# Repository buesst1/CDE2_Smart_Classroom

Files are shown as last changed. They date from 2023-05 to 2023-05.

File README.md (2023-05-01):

<!-- Improved compatibility of back to top link: See: github-link -->

<!-- logo einfügen mit Ordner namens "images" -->
<br />
<div align="center">
  <a href="https://github.com/buesst1/CDE2_Smart_Classroom">
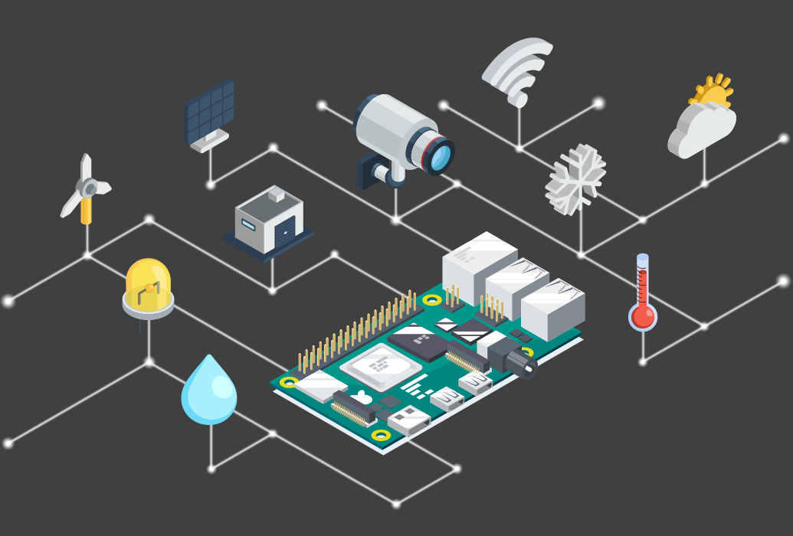
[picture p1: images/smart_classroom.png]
    
  </a>

  <h2 align="center">Smart Classroom</h3>

  <p align="center">
    In diesem Repository wird die Smart Classroom Challange des Studienganges BSc Datascience der Fachhochschule Nordwestschweiz berarbeitet.
    <br />
    Ziel dieser Challenge ist es mithilfe von IoT- Sensoren die optimalen Lüftungsparameter für ein Schulzimmer zu definieren.
    <br />
    Sie finden die Firmware, den Aufbau der Mikrokontroller, die 3D-Druckdateien der Gehäuse sowie die gesamte Datenanalyse.
  </p>
</div>

<!-- TABLE OF CONTENTS -->
  <summary><h2>Inhaltsverzeichnis<h3 /></summary>
  <ol>
    <li><a href="#projektbeschrieb">Projektbeschrieb</a></li>
    <li><a href="#Repository-Aufbau">Repository-Aufbau</a></li>
    <li><a href="#Datenablauf">Datenablauf</a></li>
    <li><a href="#Firmware">Firmware</a></li>
    <li><a href="#Hardware">Hardware</a></li>
    <li><a href="#kontakt">Kontakt</a></li>
  </ol>

<!-- PROJEKTBESCHRIEB -->
### Projektbeschrieb
Mittels verschiedenen Mikrokontroller und Sensoren wird eine automatisierte Datenübertragung auf eine Relationale Datenbank gewährleistet.
<br />
Die Daten wurden im Schulzimmer einer Primarklasse erhoben und anschliessend in diversen Jupyter Notebooks analysiert.
<br />
Um die Mikrokontroller zu schützen wurden Gehäuse konstruiert und anschliessend mit einem SLS 3D-Drucker produziert.
<br />

<p align="right">(<a href="#readme-top">back to top</a>)</p>

<!-- Repository-Aufbau -->
### Repository-Aufbau

:file_folder: Abgabe komplett -> Alle benötigten Dateien und Skripte in einem Ordner zusammengefasst <br />
:file_folder: Box -> Enthält die STL-Dateien für den 3D-Druck der Gehäuse <br />
:file_folder: Hardware -> Die wichtigsten Informationen und Beschriebe der Hardware <br />

<p align="right">(<a href="#readme-top">back to top</a>)</p>

<!-- Datenablauf -->
### Datenablauf

Die Sensordaten wurden insgesamt von drei Mikrokontroller aufgenommen und mittels BLE an einen Raspberrypi zero gesendet.
Dieser sendete Die Daten über Wlan an einen Server, welcher wiederum die Daten an die REST API der Datenbank sendet.

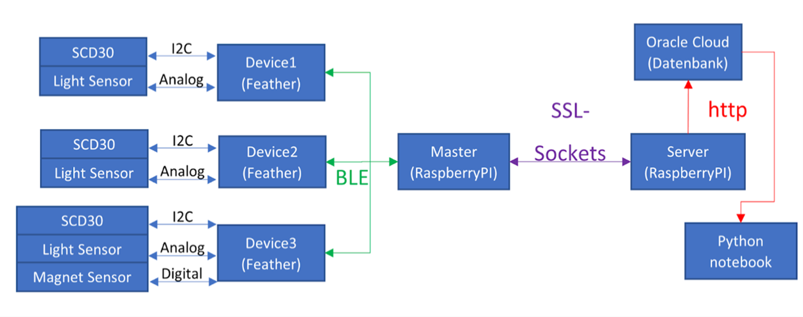
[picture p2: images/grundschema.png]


<p align="right">(<a href="#readme-top">back to top</a>)</p>

<!-- Firmware -->
### Firmware

**Ablauf**: <br />
Der Feather beginnt zu advertizen und wartet auf eine Verbindung vom Master.
Sobald eine Verbindung aufgebaut wurde, wird das Advertising gestoppt und auf den Lese-Befehl vom Master gewartet.
Wird dieser Befehl erteilt, werden die Sensoren ausgelesen, zu einem JSON konvertiert und an den Master gesendet. Der Master schliesst nun die Verbindung und der Feather geht in einen light-Sleep für 20s (um Strom zu sparen). Nun beginnt der ganze Prozess von vorne.
Sollte ein Fehler auftreten, beginnt der Advertising Prozess wieder von vorne.

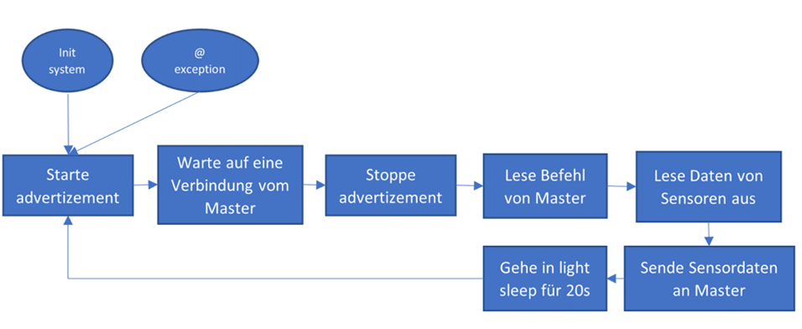
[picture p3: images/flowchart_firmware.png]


<p align="right">(<a href="#readme-top">back to top</a>)</p>

<!-- Hardware -->
### Hardware

Folgende Hardware wurde verwendet:

<b>Mikrokontroller:</b>
* Feather esp32
* Raspberry pi zero

<b>Sensoren:</b>
* SCD30
* Light Sensor
* Magnet Sensor

Die Feather esp32 Mikrokontroller wurden zusätzlich mit einem LIPO akku Betrieben.

<p align="right">(<a href="#readme-top">back to top</a>)</p>

<!-- KONTAKT -->
### Kontakt

Yannic Lais - [@yalais](https://github.com/yalais) <br />
Tobias Buess - [@buesst1](https://github.com/marvinvr) <br />
Luca Mazzotta - [@focusedluca](https://github.com/focusedluca)

<p align="right">(<a href="#readme-top">back to top</a>)</p>

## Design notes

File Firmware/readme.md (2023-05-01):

#Firmware updated: https://learn.adafruit.com/introducing-the-adafruit-nrf52840-feather/circuitpython
#load firmare on Feather:
-> delete everything from Feather -> drag and drop: lib, boot.py, code.py, config -> adjust config file parameters to your needs (see below)

#config gile configuration:
Device1: CO2_Sensor,Light_Sensor
Device2: CO2_Sensor,Light_Sensor
Device3: CO2_Sensor,Light_Sensor,Magnetic_Sensors

#Magnetic Sensors: 
    -S1 (Window1A): Pin5
    -S2 (Window2B): Pin6
    -S3 (Window3A): Pin9
    -S4 (Window4B): Pin10
    -S5 (Window5A): Pin11

->result = True: No electrical connection between Sx and GND
->result = False: Electrical connection between Sx and GND

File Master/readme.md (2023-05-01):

#installation von os und libraries (siehe guide: https://learn.adafruit.com/circuitpython-ble-libraries-on-any-computer/getting-python-on-your-host-computer)
->das installierte betriebssystem lautet: Raspberry pi OS Lite (aktiviere ssh over usb mit wifi: https://desertbot.io/blog/ssh-into-pi-zero-over-usb https://desertbot.io/blog/setup-pi-zero-w-headless-wifi)
-sudo apt-get update && sudo apt-get upgrade
-sudo apt install python3-pip -> pip3/python3 installieren (nie sudo pip3 verwenden (libraries können beschädigt werden))

->libraries installieren
-pip3 install --upgrade adafruit-blinka-bleio adafruit-circuitpython-ble iterators -> installation von ble und iterators librariy

->benutzer zu bluetooth group hinzufügen
-sudo usermod -a -G bluetooth $USER
-sudo reboot

->master script an raspi senden (siehe unten)
-pscp C:\Users\tobia\OneDrive\Dokumente\GitHub\CDE2_Smart_Classroom\Master\master.py pi@raspberrypi.local:/home/pi/master.py

->Auto run hinzufügen more:(https://www.interelectronix.com/raspberry-pi-4-autostart-qt-application-during-boot.html)
-cd /etc/systemd/system && sudo nano master.service -> folgender text innerhalb der brackets unten einfügen
"
[Unit]
Description=SmartClassroom master software
After=network-online.target
Wants=network-online.target

[Service]
Type=simple
User=pi
Group=pi
WorkingDirectory=/home/pi/
ExecStart=/usr/bin/python3 /home/pi/master.py

[Install]
WantedBy=multi-user.target
"

-sudo systemctl enable master.service -> enable service
-sudo systemctl disable getty@tty1 && sudo systemctl mask plymouth-start.service

->status des services abrufen
-sudo systemctl status master.service -> status abrufen

#weitere nützliche tools
->um dateien über ssh an den rpi zu senden kann folgender command im cmd verwendet werden:
-pscp source_file_name userid@server_name:/path/destination_file_name -> beispiel: pscp C:\Users\tobia\OneDrive\Dokumente\GitHub\CDE2_Smart_Classroom\Master\master.py pi@raspberrypi.local:/home/pi/master.py

pscp C:\Users\yanni\Documents\GitHub\CDE2_Smart_Classroom\Master\master.py pi@raspberrypi.local:/home/pi/master.py

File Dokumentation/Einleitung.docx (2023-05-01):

Einleitung

Im folgenden Bericht erfahren Sie mehr über den Einfluss von Lüften auf die Co2-konzentration eines Raumes. Für die Untersuchungen wurde über einen Zeitraum von über drei Wochen mittels mehreren Microcontroler und diversen Sensoren Daten erhoben. Diese wurden mittels HTTPS-Protokoll an einen Server und anschliessen mittel POST-Befehl in eine Relationale-Datenbank gespeichert. Für die Datenübertragung wurde in Python und Circuit-Python hauptsächlich mit der Library Ada-Fruit gearbeitet.
Letztlich wurden die Daten in Python explorativ analysiert und die Ergebnisse visuell dargestellt. In der Fragestellung wurden die Dauer und Frequenz vom Lüften einer Schulklasse und deren Einfluss auf den Co2-Wert untersucht. Zudem wurden weitere Einflüsse wie Helligkeit, Temperatur, Luftfeuchtigkeit und Personenanzahl gemessen und analysiert. Die Messungen wurden in einer 3. Klasse in einem älteren Schulhaus ohne externe Lüftung durchgeführt.

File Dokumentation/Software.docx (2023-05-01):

Firmware (Feather / Circuitpython):

MainLoop

Manager

Bluetooth

Magnetic_Sensor

Light_Sensor

SCD30_Sensor

BatteryVoltage

- Auf BLE Verbindung warten
- BLE Message lesen
- BLE Message senden
- Messung starten / Resultate erhalten
- Init
- lesen
- Init
- lesen
- Init
- lesen
- Init
- Lesen
- Schreiben
- Auf Verbindung warten
- Init
- lesen
- busio.I2C lib
- adafruit_scd30.SCD30 lib
- Analogio lib
- Digitalio lib
- Adafruit_ble lib
- Analogio lib

logger

- Schreiben (global)

watchdog

- Init

Starte advertizement

Warte auf eine Verbindung vom Master

Stoppe advertizement

Lese Befehl von Master

Lese Daten von Sensoren aus

Sende Sensordaten an Master

Gehe in light sleep für 20s

Init system

@ exception

Master (RaspberryPI / Python):

logger

Schreiben (global)

MainLoop

Bluetooth

- Adafruit_ble lib
- Messungen auslösen / Ergebnisse lesen

Cache

- Lesen
- Schreiben
- löschen

SSL

- Messungen senden

Scanne nach advertizements

Verbinde auf nächsten adverzizender slave

Sende Lese-Befehl

Lese & speichere Antwort (Messung)

Schliesse Verbindung

Noch Advertizements vorhanden

Lese noch vorhandene Messungen vom Cache

Bereits auf alle

Advert. verbunden

Verbinde zum Server

Cache neue Messung

Fehlgeschlagen

Sende Daten & Empfange confirmation

Erfolgr.

Fehlgeschlagen

oder fehlerhafte confirmation

Cache löschen

Erfolgr.

Init system

Warte 30s

@ exception

Server (RaspberryPI / Python)

MainLoop

SSL

ErrorCheck

Database

Email

- Listen to port
- Accept client
- Read from client
- Write to client
- Init
- Read buffered measurements
- Init
- Check measurements
- Get Errors
- Init
- Send status
- Send master timeout
- Send master reconnect
- Init
- store measurement

Listen & accept client (master)

Read data (measurements)

Check & Store data in Data storage

Send positive confirmation

Send negative confirmation

Erfolgr.

Fehlgeschl.

Close connection

@ ssl exception

SSL (Separate Thread)

Data storage

Wait until data in Data storage

Read & delete data from Data storage

Check data from storage & store errors

Send correct data to database (if sending not successful -> buffer Data )

Try send not already sent Data to DB & send status email containing errors every 60 min & send email if no data received from master for more than 10 min

While no data received

Init system

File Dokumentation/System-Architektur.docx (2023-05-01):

Interfaces / Protocols:

Device1
(Feather)

Device2
(Feather)

Device3
(Feather)

Master
(RaspberryPI)

Server
(RaspberryPI)

Oracle Cloud
(Datenbank)

BLE

SSL-

Sockets

http

SCD30

I2C

Light Sensor

Analog

SCD30

I2C

Light Sensor

Analog

SCD30

I2C

Light Sensor

Analog

Magnet Sensor

Digital

Python notebook

Protokolle:

- I2C:
  - https://www.mikrocontroller.net/articles/I%C2%B2C
- BLE:
  - Custom:
    - Master -> DeviceX:
      - Command als string («measure_request»)
    - DeviceX -> Master:
      - Messung als json
        - Json:
          - { 'sensorNameX’: {‘messungX’:’value, ‘messungY’:’value’, …},  ‘sensorNameY’: {‘messungX’:’value’, ‘messungY’:’value’, …},  … }
- SSL-Sockets:
  - Custom:
    - Master -> Server:
      - Messungen als string mit Format: «data~’messung1’;’messung2’;…»
        - Json:
          - { «timeStamp»:’timestamp of measurements’,  «data»:{‘devNameX’:’jsonOfDev.’, ‘devNameX’:’jsonOfDev.’, …} }
    - Server -> Master:
      - Antwort als string («failed» / «confirmed») je nach dem ob die daten erfolgreich empfangen und verarbeitet wurden
- http:
  - rest API:
    - https://developer.oracle.com/databases/oracle-rest-data-services-for-python-developers.html

Dataflow vom Beginn einer Messung bis zur Persistierung:

1. Device1 – 3 beginnen zu Advertisen
2. Master versucht die Advertisements der Devices zu finden
3. Master speichert jetzige Zeit
4. Master versucht sich mit einem Device dessen Advertisement gefunden wurde (und noch nicht versucht wurde zu verbinden) zu verbinden
5. Master sendet Befehl: «measure_request»
6. Device empfängt Befehl und beginnt die Angeschlossenen Sensoren auszulesen
7. Device Device konvertiert die Resultate/Fehlermeldung(en) der Messung zu einem Json und sendet diese zurück an den Master
8. Master speichert die Messergebnisse / Fehlermeldungen und schliesst die Verbindung
9. Schritte 4 bis werden nun solange wiederholt, bis mit allen Devices (dessen Advertizement gefunden wurde) wenigstens ein Verbindungsversuch stattgefunden hat
10. Master konvertiert nun Messresultate / Fehlermeldungen mit dem zuvor gespeicherten Zeitstempel zu einem Json
11. Master versucht sich nun mit dem Server zu verbinden
12. Server akzeptiert die Verbindung
13. Master sendet alle vorhandenen Messungen (neue und cached) an Server
14. Server empfängt daten und versucht diese zu verarbeiten und speichert die in der Datenbank
15. Bei erfolgreicher Verarbeitung sendet der Server «confirmed» an den Master zurück (ansonnsten wird «failed» gesendet)
16. Master empfängt Antwort von Server
17. Falls die Verbindung zum Server während der Transaktion fehlschlägt (Verbindungsabbruch oder «failed» empfangen) oder diese erst gar nicht aufgebaut werden kann, speichert der Master die neue Messung im «cache» file

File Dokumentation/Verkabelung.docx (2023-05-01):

Device 1-2:

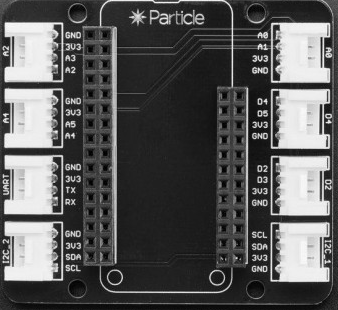
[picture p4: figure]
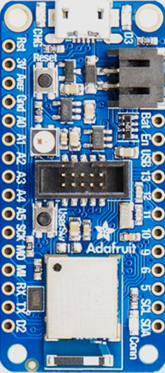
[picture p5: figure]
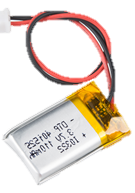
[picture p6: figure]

Device 3:

Window1A

Window2B

Window3A

Window4B

Window5A

Master:

Mittels MicroUSB via einem Handy Netzteil an einer 5V Spannungsquelle verbunden.
Mittels Wifi ans Internet angebunden.

Server:

Mittels MicroUSB via einem Handy Netzteil an einer 5V Spannungsquelle verbunden.
Mittels Ethernet ans Internet angebunden.

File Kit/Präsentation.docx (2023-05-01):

(Luca)

Folie 1:

- Begrüssung
- Unser Thema
- Warum das Thema? / Wie sind wir vorgegangen? / Warum sind wir so vorgegangen? (Ziel)

(Tobias)

Folie 2/3:

- Brainstorming (Was wir dachten was wir brauchen werden.)
- Selbsteinschätzung der einzelnen Themen
- Themen nach Wichtigkeit gefiltert. (Nicht jeder kann alles können)
- Aufgaben gem. Einschätzung aufgeteilt.

(Yannic)

Folie 3:

- Probleme, die aufgetreten sind, aufzählen, in Bezug auf Aufgabenaufteilung
- Massnahme 1 erklären, Grund für Massnahmen (für Abgabe)
- Wissenstand vor Abgabe präsentieren
- Massnahme 2 erklären, Grund für Massnahmen (für Prüfungen)
- Wissenstand vor Prüfungen präsentieren und erklären, dass es noch nicht fertig ist.

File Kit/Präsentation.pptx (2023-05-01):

## Kollaboration in Teams

Yannic Lais, Tobias Buess, Luca Mazzotta, FHNW, Hochschule für Technik

Wissensaustausch

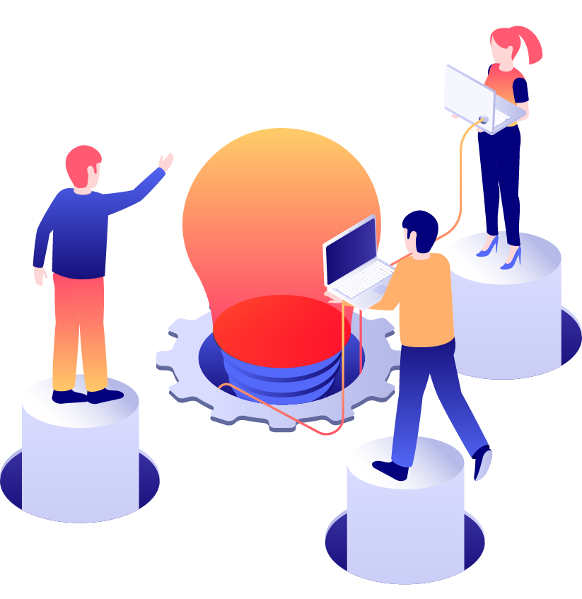
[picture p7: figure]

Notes:
Hallo Zusammen und herzlich willkommen zu unserer Kit Präsentation.
Wie ihr bereits unten links entnehmen, könnt besteht unsere Gruppe aus 3 Teilnehmer:
Yannic Lais, Tobias Buess und mich Luca Mazzotta.
Wir haben uns am Anfang dieses Semesters entschieden die Challenge «Smart Classroom» zusammen zu absolvieren, und noch bevor wir anfangs wussten, was uns im Modul «KIT» erwartet, haben wir uns ebenfalls geeinigt uns für das Modul «Kit» einzuschreiben und auch dieses Modul zusammen zu absolvieren.

Vielleicht mal kurz paar Hintergrundinformationen über unser Team:

Yannic und Ich haben bereits im ersten Semester zusammen eine Challenge gemacht und kannten uns dementsprechend ein bisschen.
Jedoch hatten wir beide mit Tobias noch nicht zusammengearbeitet.
Ausserdem ist auch wichtig zu erwähnen, dass alle von uns Quereinsteiger im Studium sind, dh. dass niemand von uns eine Informatiker-Lehre gemacht hat.
Tobias → Elektroniker
Yannic → Polymechaniker
Und ich → Zeichner, Fachrichtung Ingenieurbau

Diese Hintergrundinformationen waren wichtig für uns als Team um einen ersten Eindruck zu erschaffen wo wir als Team stehen.

Ausserdem wurde uns dann auch schnell bewusst, dass was die Challenge angeht, wir uns noch viel Wissen aneignen mussten.
Da niemand von uns bereits Vorwissen hatte (dazu aber später mehr)

In der Kick-off Stunde der Challenge, wurde uns die Challenge vorgestellt und die Termine für Abgaben wurden ebenfalls erwähnt.
Das war der Zeitpunkt an dem wir wussten, das die Zeit ein grosser Faktor sein würde für unsere Arbeit.

Wir müssen uns das Wissen aneignen, gleichzeitig das Skript für die Sensoren schreiben, die Datenbank erstellen und uns Gedanken machen wie wir die Daten auswerten?
Spätestens da haben wir gemerkt, dass wir die Arbeit aufteilen müssen um es Zeitlich hinzubekommen.

Jedoch war uns klar, dass trotzdem jeder aus dem Team alles wissen muss.
Zwar nicht alles gleich gut, jedoch alles genug gut um evtl. für andere einzuspringen und für die Einzelprüfung die nach der Präsentation folgt.

Da wussten wir das „Wissensaustausch“ eine grosse Rolle dieses Semester spielen würde.

Wir waren uns bewusst, dass wir unser Wissen austauschen müssen. Damit sich nicht jeder mit allen Themen beschäftigen muss, jedoch alles im Projekt versteht.
Dies war auch der Grund warum wir uns im Modul „Kit “ uns für das Thema „Wissensaustausch“ entschieden haben.

Wie wir Vorgegangen sind was die Arbeitsaufteilung angeht und somit wer sich welches Wissen aneignet, wird euch Tobias im Anschluss erklären
Wie der Wissensaustasuch stattgefunden hat und was für Gedanken wir uns dazu gemacht haben wird euch Yannic erzählen.

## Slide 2

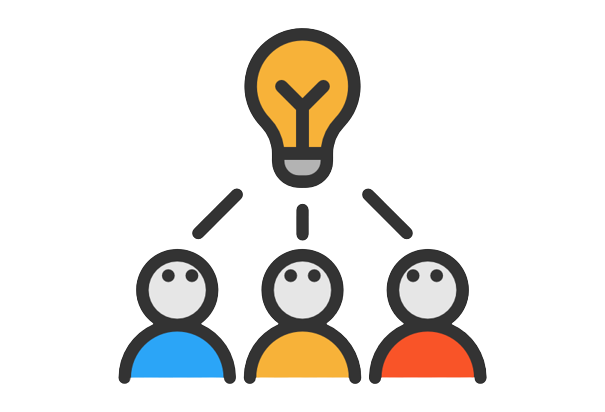
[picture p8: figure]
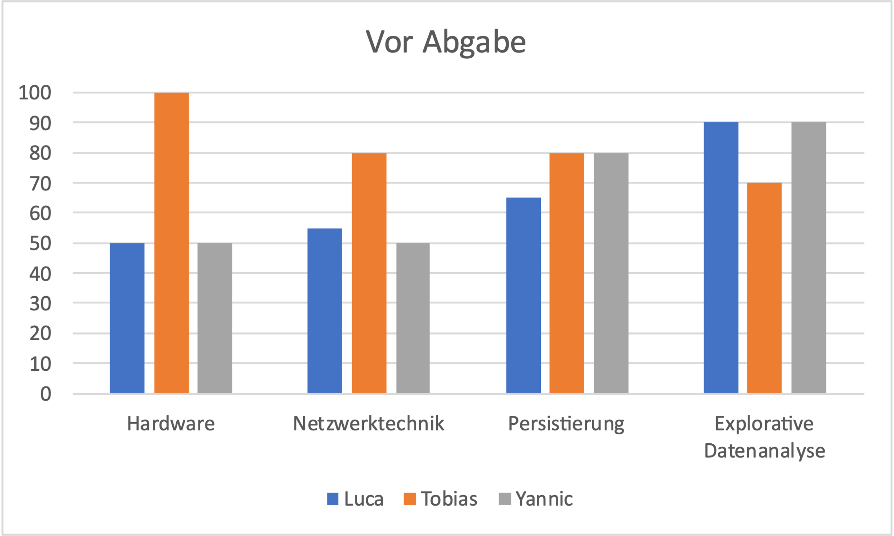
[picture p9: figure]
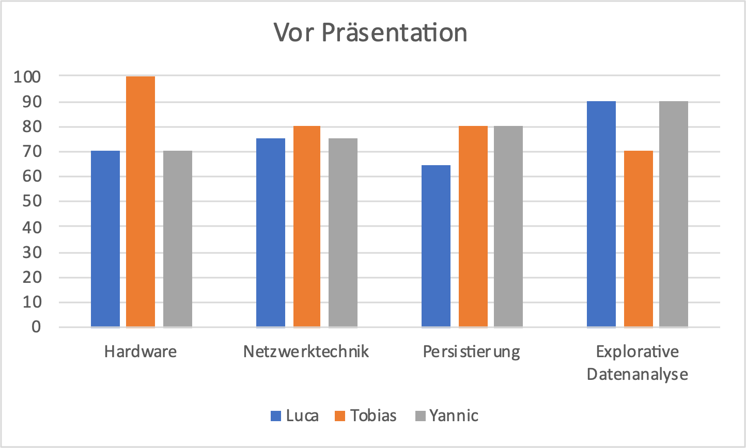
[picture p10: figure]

(In Bearbeitung)

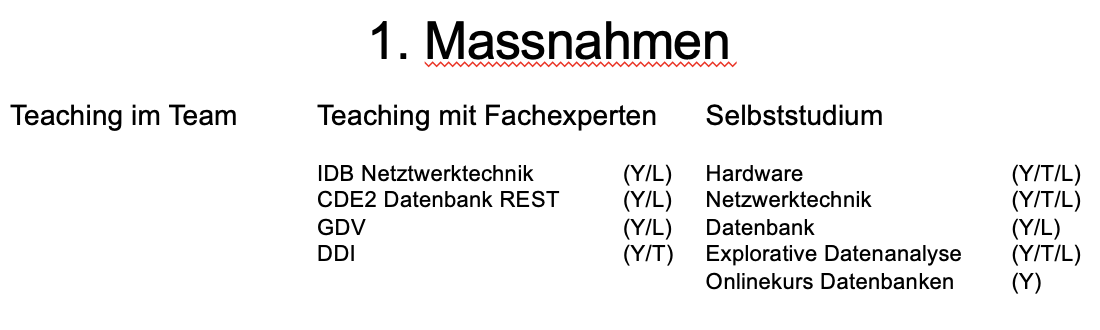
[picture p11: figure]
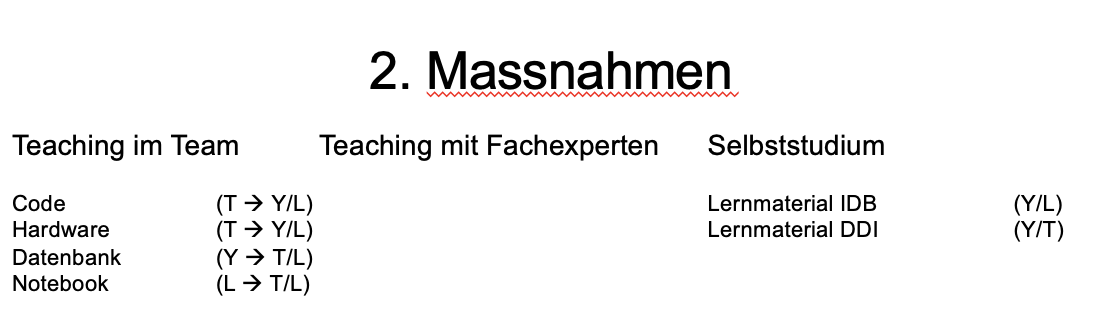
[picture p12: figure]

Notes: Damit wir Wissenslücken gezielt schliessen konnten, mussten wir erst einmal eine Strategie erarbeiten, welche es uns ermöglich unsere Ziele zu erreichen.

Zuerst mussten wir dazu erst einmal wissen, was wir überhaupt wissen müssen um unsere Challenge bearbeiten zu können.
Dazu haben wir uns zusammengesetzt und Ideen gesammelt wie unsere Challenge lösen können und was wir dazu benötigen.
Als wir uns für eine Lösungsstragegie entschieden haben, begannen wir aufzulisten, in was für Bereichen wir Wissen benötigen.

Nach diesen Wissensbereichen, haben wir nun anschliessend eine Selbsteinschätzung abgegeben wir fit wir in den einzelnen Bereichen waren.
Unsere Selbsteinschätzungen haben wir als nächstes in der Gruppe besprochen und zusammengeführt.

Unser Problem war nun, dass wir allerdings unsere Wissensveranschaulichung zu detailiert strukturiert haben, um eine Gute einschätzung abgeben zu können.
Deshalb mussten wir die Wissensbereiche etwas filtern und komprimieren.
Hierbei haben wir Bereiche, welche zueinander gehörten als ein einzelne Zusammengefasst.
Ausserdem haben wir uns anschliessend nur auf die 4 wichtigsten Wissensbereiche konzentriert, welche von Nöten waren um unsere Challenge bearbeiten zu können.

Dadurch konnten wir uns ein grobes Bild machen, wer über welches Wissen verfügt und in einem Ersten Schritt somit entscheiden, wer welche Aufgabe zugeteilt bekommt.

Nun konnten wir die Challenge bearbeiten und unser Fehlendes Wissen unserer Zugeteilten Aufgaben über verschiedene Wege aneignen.
Unser Team blieb natürlich während der Bearbeitung in einem intensiven Austausch was das Wissen und auch Vortschritte betrifft.

Nach Fertigstellung der Challenge Bearbeitung (Nach Abgabe aber vor Vortrag) machten wir nun wieder eine Selbsteinschätzung zu unseren Wissensbereichen.
Somit konnten wir sehen, welches zusätzliche Wissen gewonnen wurde.

Da wir für unseren Vortrag der Challenge allerdings in jedem Bereich über alles bescheid wissen müssen, sollten alle Balken etwa gleich hoch sein.
Somit konnten wir also noch weitere Massnahmen treffen um die Balken ausgleichen zu versuchen.

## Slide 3

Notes: Wie man sehen kann, haben wir uns für die Bereiche "Hardware", "Netzwerktechnik", "Persistierung" und "Explorative Datenanalyse" entschieden.
Dies sind die Wissensbereiche welche wir für unsere Challenge bearbeitung zwingend benötigten.
Und dies sind nun die Resultate unserer Selbsteinschätzung vor der Challenge Bearbeitung.

Ich habe nun einen grossen Wissensvorsprung im Bereich "Hardware".
Luca allerdings hat einen Wissensvorsprung im Bereich "Explorative Datenanalyse"
Deshalb haben wir uns dazu entschieden, dass ich Aufgaben im Bereich der Hardware übernehme und Luca Aufgaben in der Datenanalyse.

In den beiden anderen Bereichen hatten wir alle etwa gleich viel Wissen, weshalb Yannic sich hauptsächling um die Datenbank also die Persistierung kümmerte.

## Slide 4

1. Massnahmen

Teaching mit Fachexperten
IDB Netztwerktechnik (Y/L)
CDE2 Datenbank REST (Y/L)
GDV (Y/L)
DDI (Y/T)

Teaching im Team

Selbststudium
Hardware (Y/T/L)
Netzwerktechnik (Y/T/L)
Datenbank (Y/L)
Explorative Datenanalyse (Y/T/L)
Onlinekurs Datenbanken (Y)

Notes: Somit bestanden unsere ersten Massnahmen zum benötigten Wissenserwerb hauptsächlich aus Selbststudium sowie einigen Inputs auf Seite der Fachexperten.
Der Wissenserwerb zielte hier Hauptsächlich auf die Aufgaben ab, welche wie vorhin beschrieben aufgeteilt wurden.
Um die aufgeteilten Aufgaben erfolgreich zu bestreiten musste vor der ‘spezialisierung’ erst noch ein Grundgerüst in Netzwerktechnik und Hardware von Luca und mir aufgebaut werden.
Welches durch angefragten Teachings und Selbststudium erfolgreich gelang.

Massnahmen hauptsächlich aus Selbststudium und Teachings von Fachexperten
-Wissenserwerb zielte auf das erfolgreiche bestreiten der individuellen Aufgaben ab
-Grundgerüst in Netztwerktechnik und Hardware -> Angefragtes Teaching von Fachexperte erzielte gute Ergebnisse

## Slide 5

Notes: Vor der Abgabe machten wir wieder eine Selbsteinschätzung des vorhandenen Wissens im Team.
Deutlich zu sehen ist das gestiegene Wissen in den einzelnen Domänen sowie verringerungen der Wissenslücke, welche hauptsächlich anderen Modulen geschuldet ist (Tobias persistierung).
Die nächsten Massnahmen sollten darauf abzielen nun das Wissen unter allen Teammitgliedern möglichst gut anzugleichen.
Denn für die mündliche Abschlussnote müssen alle Teammitglieder im Stande sein Fragen zu allen Thematiken zu beantworten.

2. Selbsteinschätzung im Team
Gestiegenes Wissen in den einzelnen Domänen sowie Verringerung der Wissenslücken der einzelnen Teammitglieder
Wöchentliche Treffen und Besprechung der Probleme
2. Massnahmen das Wissen angleichen -> benötigt für die Abschlussprüfung

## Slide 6

2. Massnahmen

Teaching mit Fachexperten

Teaching im Team
Code (T → Y/L)
Hardware (T → Y/L)
Datenbank (Y → T/L)
Notebook (L → T/L)

Selbststudium
Lernmaterial IDB (Y/L)
Lernmaterial DDI (Y/T)

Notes: Somit bestanden die weiteren Massnahmen hauptsächlich aus Teachings im Team sowie aus Selbststudium.
Besonders die Teachings versprachen guten Erfolg, da hier viele individuelle Fragen ausführlich beantwortet wurden.
Das auch deshalb, weil gezielt mehrere Stunden dafür im Zeitplan vorgesehen sind.

2. Massnahmen bestanden hauptsächlich aus Teachings und Selbststudium
Teachings versprachen grossen Erfolg -> individuelle fragen können ausführlich besprochen werden
Zeit wurde und muss dringen im Zeitplan berücksichtigt werden

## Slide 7

(In Bearbeitung)

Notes: Momentan sind noch nicht alle Massnahmen erfolgt, somit ist es zu früh eine 3. Evaluationsrunde im Team zu bestreiten, diese wird jedoch ca. ein - zwei Wochen vor der Prüfung noch gemacht.
Individuelle 3. Massnahmen

Zu früh für 3. Evaluationsrunde-> wird in den nächsten 1-2 Wochen nachgeholt

## Vielen Dank für Ihre Aufmerksamkeit. Fragen?

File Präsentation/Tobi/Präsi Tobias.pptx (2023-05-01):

## Teil Tobias

## Lösungsansatz

CO2, Temperatur, Luftfeuchtigkeit, Helligkeit

+ Anz. off. Fenster

Sensorpaket (Device 3)

Sensorpaket (Device 1)

Datenpaket Device 1
{
scd_30_sensor: {
CO2: 1100,
Temp: ‘read_failed’,
…
},
…
}

Sensorpaket (Device 2)

Anforderungen an System:
- Erfassung der Luftqualität und Persistierung in DB
- Fehlermeldung < 24h
- Erfassen von geöffneten Fenstern
- Messung an mehreren Orten im Raum
- Detaillierte Fehlermeldung
- Möglichst einfaches Setup (Auf-/Abbau)

BLE

Master

Sensorpaket (Device X)

Multisensor
(CO2, Temp., Luftf.)

HW Interface

Mikrocontroller

SSL

Measurement
{
Timestamp: 23.06.2022 13:35:03,
Device 1: DP D1,
Device 2: …,
Device 3: …
}

sensor

Bluetooth

Magnetsensor /
Helligkeitssensor /
etc.

Akku

U-Überwachung

sensor

Server

empfänger

HTTP

sensor

datenbank

Datenbank

## Ablauf einer Messung

Device 1

Device 2

Device 3

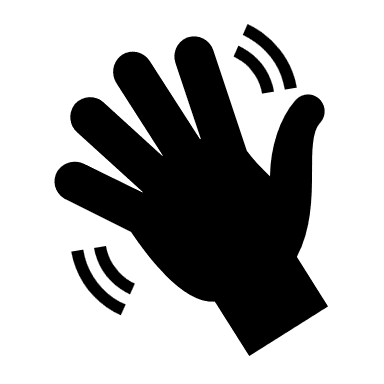
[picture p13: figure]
Winkegeste mit einfarbiger Füllung

Anfrage

json

Anfrage

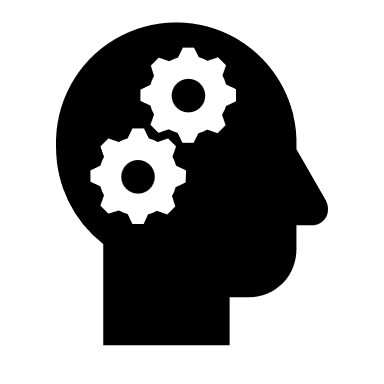
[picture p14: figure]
Kopf mit Zahnrädern mit einfarbiger Füllung

Master

Anfrage

json

json

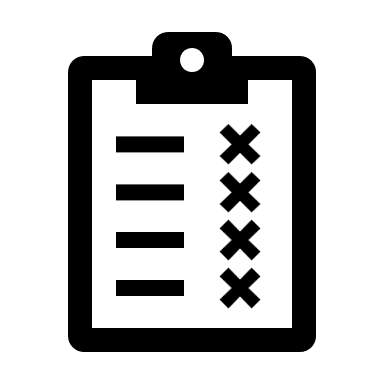
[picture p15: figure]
Klemmbrett nur Kreuze mit einfarbiger Füllung
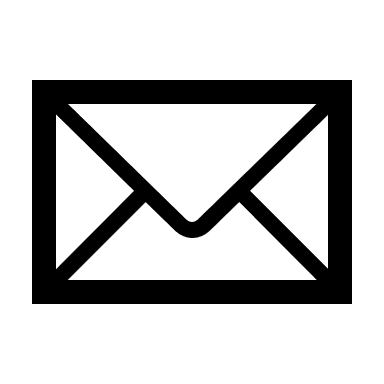
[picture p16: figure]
Umschlag mit einfarbiger Füllung

Server

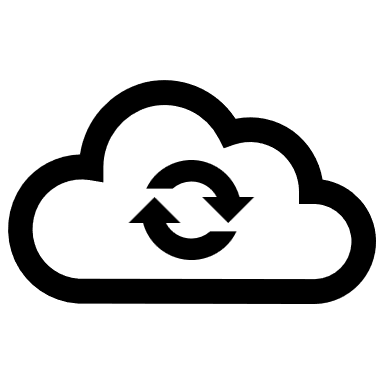
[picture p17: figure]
Synchronisierende Cloud mit einfarbiger Füllung

json

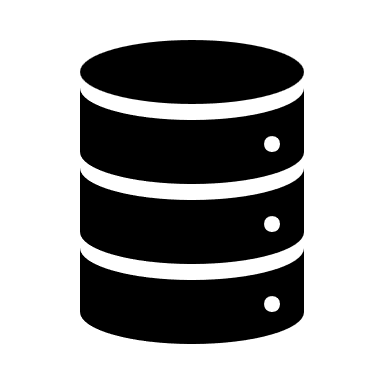
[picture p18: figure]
Datenbank mit einfarbiger Füllung
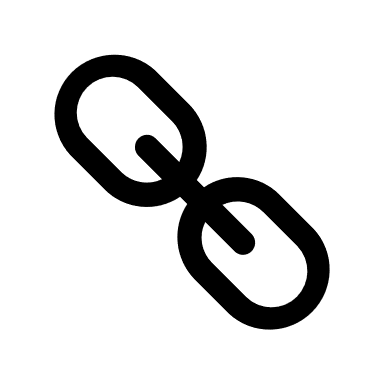
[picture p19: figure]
Link mit einfarbiger Füllung

Successful /
failed

## Datenbank

Welche Datenbank?
- Influx DB
- Oracle relational DB

Normalisiertes Schema

Schema

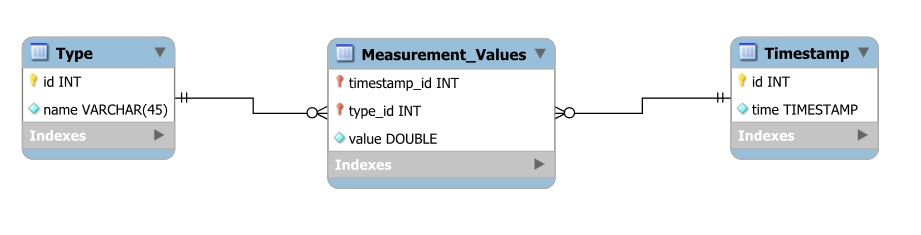
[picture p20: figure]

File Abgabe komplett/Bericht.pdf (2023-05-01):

cde2 – Smart Classroom, Bericht

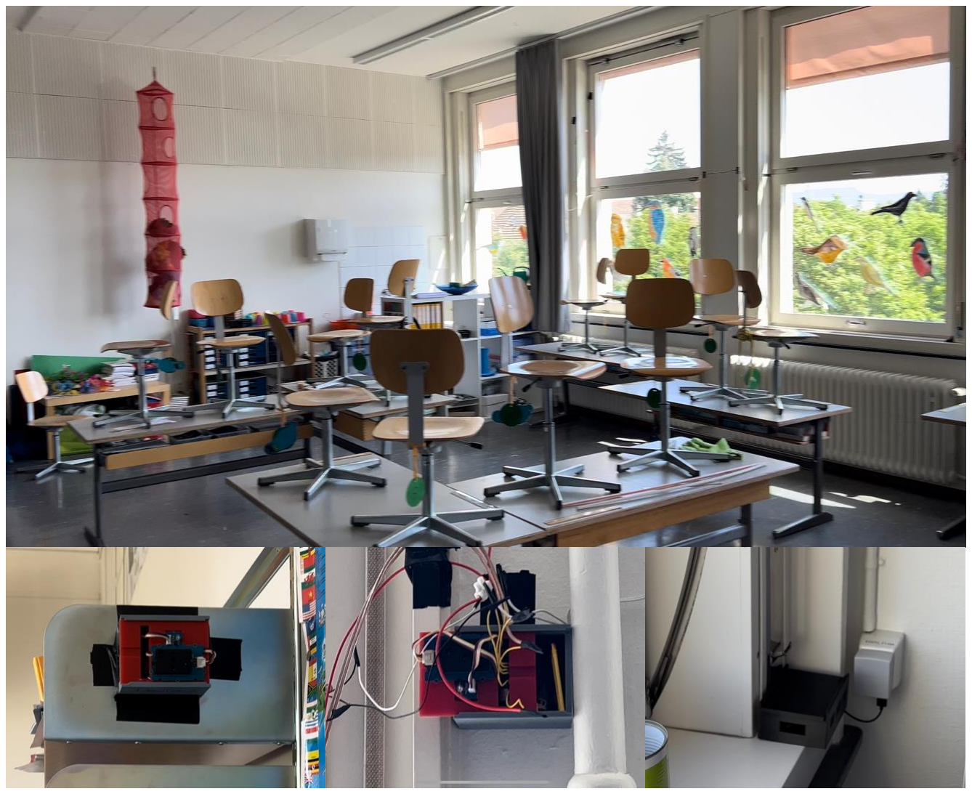
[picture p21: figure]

Fachexperte: | Jürg Luthiger Andrea Kennel Thomas Amberg
Verfasser: | Team Krokodil Tobias Buess Yannic Lais Luca Mazzotta

Datum der Abgabe: 30.05.2022

Inhaltsverzeichnis

## Einleitung

Im folgenden Bericht erfahren Sie mehr über den Einfluss von dem Lüften auf die Co2-Konzentration eines Raumes.
Für die Untersuchungen wurde über einen Zeitraum von drei Wochen mittels mehreren Microcontroller und diversen Sensoren Daten erhoben. Die erhobenen Daten von den Feather ESP32 wurden via BLE an einen Raspberry Pi Zero und von da aus per SSL-Socket an einen Server gesendet, welcher uns stündlich über allfällige Fehlermeldungen per E-Mail benachrichtigte. Anschliessend wurden die Daten mittels POST-Befehl via HTTP-Protokoll in einer Relationalen-Datenbank gespeichert. Für die Datenübertragung wurde in Python und Circuit-Python hauptsächlich mit Libraries von Ada-Fruit gearbeitet.
Durch Akkus konnten die einzelnen Microcontroller flexibel an gewünschten Standorten im Schulzimmer platzieren werden.
Letztlich wurden die Daten in Python explorativ analysiert und die Ergebnisse visuell dargestellt. In der Fragestellung wurden die Dauer und Frequenz vom Lüften einer Schulklasse und deren Einfluss auf den Co2-Wert untersucht. Zudem wurden weitere Einflüsse wie Helligkeit, Temperatur, Luftfeuchtigkeit, Schulfach und Personenanzahl gemessen und analysiert.
Die Messungen wurden im April, in der Primarschule «Gotthelf» in Basel, durchgeführt.
Im Klassenzimmer wurden 3. Klässler unterrichtet und es befand sich keine externe Lüftung im Klassenzimmer. Das Raumvolumen beträgt 190 Kubikmeter und wurde von einer unterschiedlichen Anzahl Personen genutzt.
Das System wurde so entwickelt, dass eine Erweiterung der Sensoren oder sogar Microcontroller relativ einfach realisiert werden kann.

## System-Architektur APIs/Protokolle/Datenformate

Übersicht

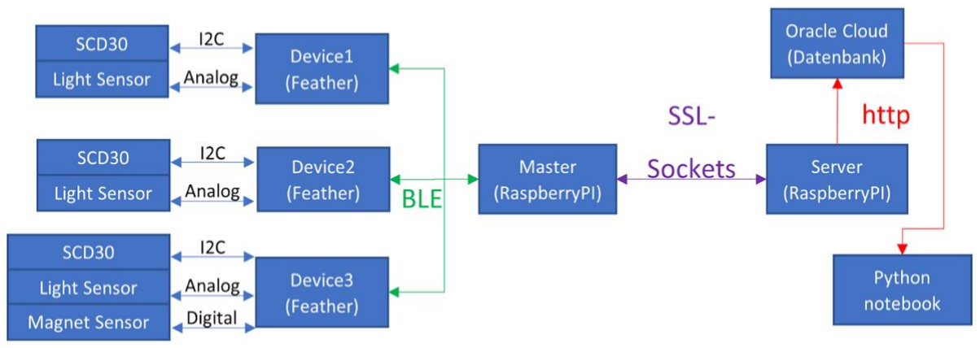
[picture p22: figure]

Unser Messsystem ist nach dem Master-Slave Prinzip aufgebaut.
Die Devices 1-3 sind Microcontroller, welche mit einem BLE-Modul ausgestattet sind. Diese hören auf den Befehl vom Master und sind somit die Slaves.
Die Verbindung zwischen den Slaves und dem Master wird mittels BLE hergestellt und die Verbindung zwischen Master und Server wird über SSL-Sockets hergestellt.
Der Server kann mittels POST-Request über http die Daten an die Oracle-Cloud senden.

Abbildung 1 Übersicht Systemarchitekur

## Protokolle

- I2C:
- https://www.mikrocontroller.net/articles/I%C2%B2C
- BLE:
- Custom:
- Master -> DeviceX:
- Command als string («measure_request»)
- DeviceX -> Master:
- Messung als json
- Json:
- {
'sensorNameX’:
{‘messungX’:’value, ‘messungY’:’value’, …},

‘sensorNameY’:
{‘messungX’:’value’, ‘messungY’:’value’, …},

…
}
- SSL-Sockets:
- Custom:
- Master -> Server:
- Messungen als string mit Format: «data~’messung1’;’messung2’;…»
- Json:
- {
«timeStamp»:’timestamp of measurements’,

«data»:{‘devNameX’:’jsonOfDev.’, ‘devNameX’:’jsonOfDev.’, …}
}
- Server -> Master:
- Antwort als string («failed» / «confirmed») je nach dem ob die daten erfolgreich empfangen und verarbeitet wurden
- http:
- rest API:
- https://developer.oracle.com/databases/oracle-rest-data-services-for-python-developers.html (https://developer.oracle.com/databases/oracle-rest-data-services-for-python-developers.html)

BLE:

Um die Daten zwischen den Slaves und dem Master effizient und stromsparend auszutauschen wird BLE verwendet.
Statt BLE kann auch Wifi verwendet werden. Allerdings braucht dieses System mehr Strom, was die Betriebsdauer des Akkus vermutlich erheblich verringert.
Der Master sendet einen einfachen String an die Slaves, um eine Messung zu starten.
Da an den Slaves verschiedene Sensoren angeschlossen sein können, und auch Fehler während den Messungen auftreten können, müssen auch Sensoren-Namen und Fehler übertragen werden können.
Dies kann man mittels verschachteltem Dictionary machen.
Dieses Dictionary wird schlussendlich im JSON-Format zurück an den Master gesendet.

SSL:

Da die einzelnen Messungen der Slaves, vom Master zum Server gelangen müssen, werden die einzelnen Messergebnisse und dem dazugehörigen Zeitstempel in einem Dictionary gespeichert.
Müssen mehrere Messungen (Somit auch mehrere Dictionaries) an den Server gesendet werden, sind diese mittels Semikolons (;) voneinander getrennt.
Der Server kann die Messung mittels ‘confirmed’ dem Master als erfolgreich verarbeitet bestätigen oder mit ‘failed’ dementieren.

http:

Die Einzelnen Messpunkte werden mittels POST-Request an die Oracle-Datenbank gesendet.

## Hardware Sensor Module/Verkabelung

Devices

Device 1 und 2 | Device 3

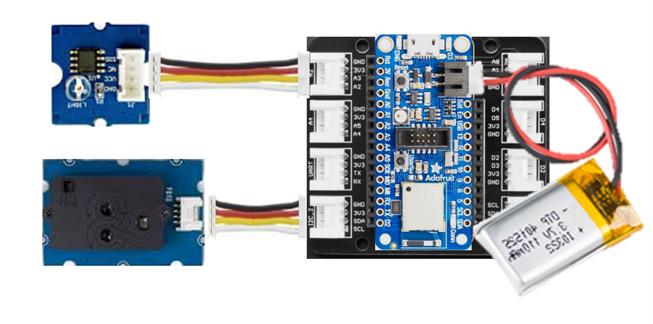
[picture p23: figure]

Master

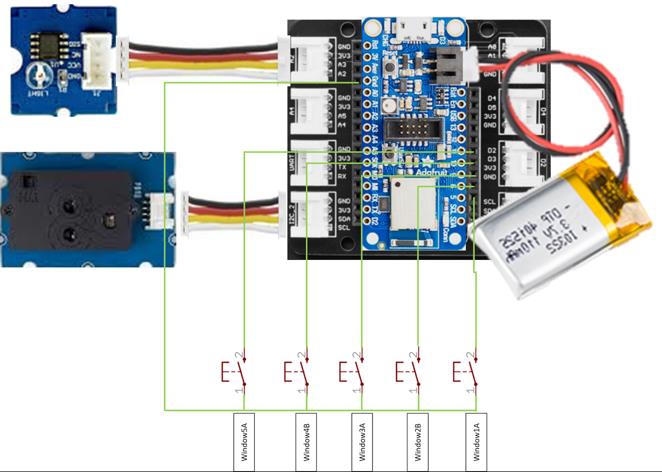
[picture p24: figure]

Der Master ist ein Raspberry PI Zero und wurde mittels eines MicroUSB-Kabels und einem Netzteil an einer 5V-Spannungsquelle angesteckt und durch WIFI mit dem Internet verbunden.

Server

Ebenfalls ein Raspberry PI 4 welcher mittels eines MicroUSB-Kabels und einem Netzteil an einer 5V-Spannungsquelle angesteckt und mittels Ethernets ans Internet angebunden.

## Software Module/Sequenzdiagramm

Firmware

Der Feather beginnt zu
advertizen und wartet auf
eine Verbindung vom
Master.
Sobald eine Verbindung
aufgebaut wurde, wird das
Advertising gestoppt und
auf den Lese-Befehl vom
Master gewartet.
Wird dieser Befehl erteilt,

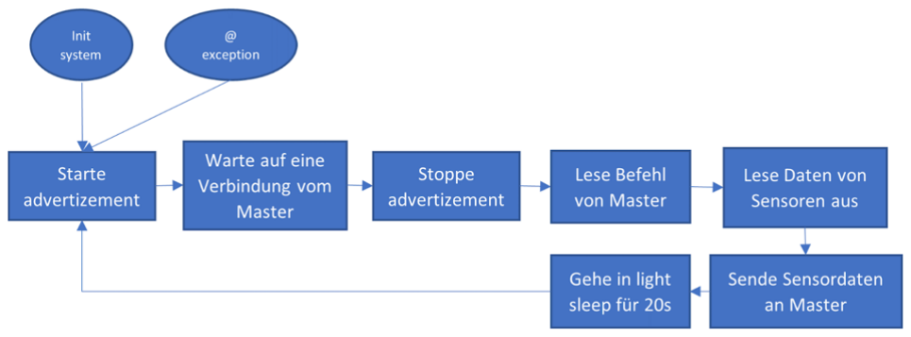
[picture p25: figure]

werden die Sensoren ausgelesen, zu einem JSON konvertiert und an den Master gesendet. Der Master schliesst nun die Verbindung und der Feather geht in einen light-Sleep für 20s (um Strom zu sparen). Nun beginnt der ganze Prozess von vorne.
Sollte ein Fehler auftreten, beginnt der Advertising Prozess wieder von vorne.

Abbildung 3 Device 1 und 2

Abbildung 2 Device 3

Abbildung 4 Übersicht Firmware

Master

Der Master beginnt nach Advertisements der Feather zu scannen.
Anschliessend verbindet sich der Master mit einem Feather, sendet den Lese-Befehl, liest die Messungen ein und speichert diese ab.
Die Verbindung wird nun wieder geschlossen.
Jetzt verbindet sich der Master mit dem nächsten verfügbaren Feather und startet den Messvorgang. Dieser Vorgang wird wiederholt, bis alle Feather mindestens einen Verbindungsversuch hinter sich
haben.

Der Master versucht sich mit dem Server zu verbinden.

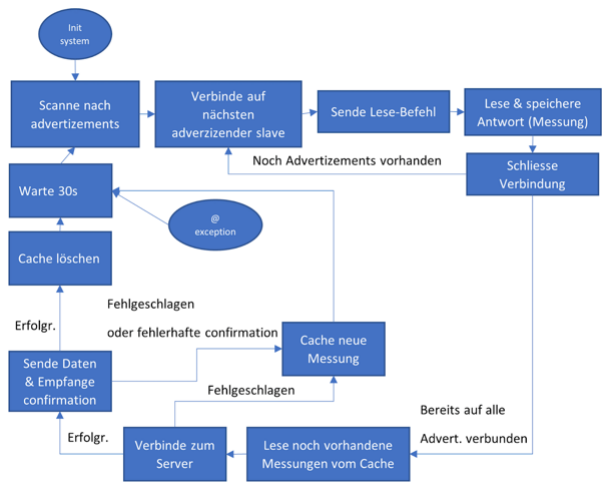
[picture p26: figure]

Schlägt dies fehl, so wird die eben gemessene Messung temporär Persistiert (Cached). Wurde die Verbindung aufgebaut, werden die Messungen gesendet und bei einer erfolgreichen Verarbeitung durch den Server, der Cache gelöscht.

Nun werden 30s gewartet, bis erneut gemessen wird.

Bei einer nicht gefangenen Exception geht der Master in einen Sleep für 30s.

Server

Der Server wartet auf eine
Verbindung vom Master.
Wurde eine Verbindung aufgebaut, so werden die Daten eingelesen, überprüft und anschliessend temporär abgespeichert.
Dem Master wird mitgeteilt, dass die Daten erfolgreich verarbeitet wurden.
Bei einem Fehler wird auch dies dem Master mitgeteilt, welcher in diesem Fall die Daten Cached und erst beim nächsten Verbindungsversuch wieder sendet.
Parallel wartet ein weiterer Thread auf die verarbeitetet Daten und speichert diese in der Oracle-Cloud-Datenbank ab.
Falls auf der Master- oder Device-

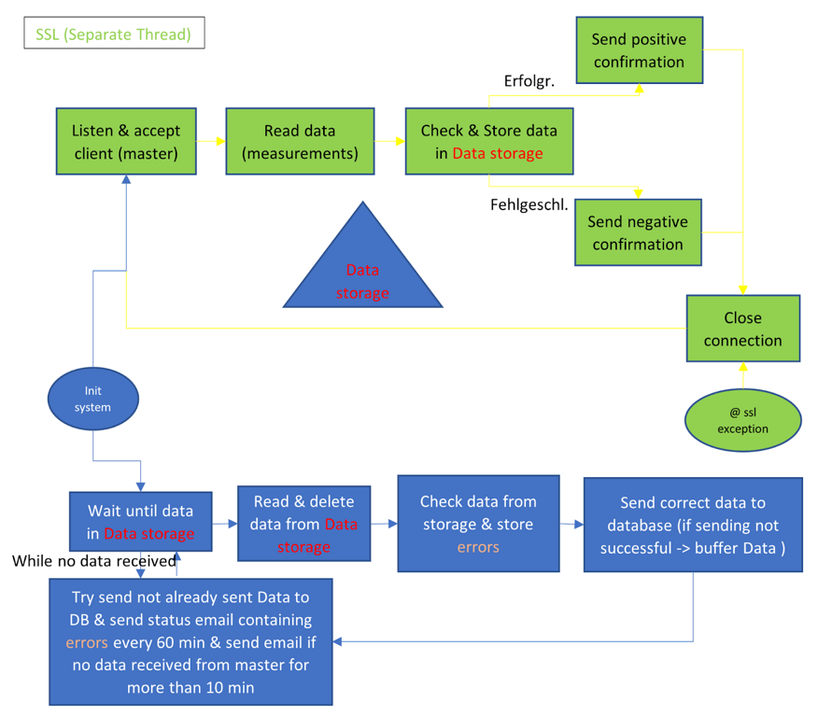
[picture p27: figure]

Seite Fehler auftreten, werden diese bei der Persistierung in die Datenbank ignoriert und stattdessen in einer stündlichen Status Email an uns gesendet.
Falls 10min vom Master keine Daten erhalten wurde, wird auch dies in einer Mail gesendet.

Abbildung 5 Übersicht Master

Abbildung 6 Übersicht Server

Flowchart


## Datenbank Entitäten/Schema/…

Persistierung

Um die produzierten Daten abzuspeichern, wurde mittels dem SQL Developer von Oracle eine Relationale Datenbank erstellt. Die Daten wurden einfachheitshalber nur in einer Tabelle abgespeichert, dies führte wegen dem kurzen Zeitraum der Messungen und der guten Planung im Voraus zu keinerlei Problemen. Anschliessend wurde ein REST-Service erstellt, mit dem die Messungen per POST-Befehl vom Server in die Datenbank gespeist wurden. Beim Verlust der Verbindung von Microcontroller zum Master oder dem Server wurden die Daten auf den Microcontroller im Cache zwischengespeichert und anschliessend in die Datenbank geladen.
Für die Datenauswertung konnten die Messdaten jederzeit mittels GET-Befehles aus der REST-API heruntergeladen werden.

Abbildung 7 Flowchart

## Erkenntnisse aus Daten

Zusammenhang Luftqualität und Lüftungs-Frequenz

Wie man anhand folgender Abbildungen erkennen kann, steigt der Co2-Wert schnell, sobald sich Personen im Klassenzimmer befinden. Hierbei spielt es fast keine Rolle, ob die Fenster offen sind oder nicht.
Sobald Pausen stattfinden, sieht man ebenfalls, wie der Co2-Wert stark sinkt.


Luftqualität in Abhängigkeit der Anzahl Personen

Wie bereits im vorherigen Kapitel erwähnt, steigt der Co2-Wert, sobald sich Personen im Klassenzimmer befinden.
Um eine genaue Aussage zu treffen, wie sehr der Co2-Wert steigt in Abhängigkeit mit der Anzahl Personen bräuchte man mehr Daten, da man solche Aussagen nur treffen kann unter gleichen Bedingungen (In unserem Falle, wenn genau die gleichen Fenster geöffnet sind). Nichtdestotrotz kann man mit unseren Daten beweisen, dass der Co2-Wert schneller ansteigt, wenn mehrere Personen im Zimmer sind.
Um dies zu beweisen, hat man im Datensatz Observationen gesucht, die dieselbe Anzahl an gekippten und an offenen Fenstern haben aber gleichzeitig unterschiedliche «Anzahl Personen im Raum» haben, danach hat man die Steigung des Co2-Werts geplottet und so verglichen.
Abbildung 10 Co2 Verlauf vom 04.04.2022 | Abbildung 9 Co2 Verlauf vom 08.04.2022

Abbildung 8 Co2 Verlauf vom 27.04.2022


Abbildung 12 Co2 Verlauf nach Eintritt von Personen (1 Fenster gekippt & 2 Fenster offen)


Abbildung 11 Co2 Verlauf nach Eintritt von Personen (2 Fenster gekippt & 1 Fenster offen)

Optimaler Zeitpunkt zum lüften

Der optimale Zeitpunkt zum Lüften, kann anhand unserer Daten nicht ermittelt werden.
Es wurde im Klassenzimmer konstant gelüftet (Wahrscheinlich u.a. auch wegen Covid), somit wurde im Klassenzimmer abgesehen von Messfehlern, nie ein Co2-Wert von über 1200 ppm (Kritischer Wert) gemessen.
Da der Co2-Wert bei geschlossenem Fenster annährend linear steigt, kann man mittels linearer Regression ein Zeitpunkt berechnen lassen, wann der Co2-Wert 1200 ppm erreichen würde. In diesem Beispiel wäre, dies der Zeitpunkt, an dem die Personen das Klassenzimmer verlassen sollten und im Klassenzimmer gelüftet werden sollte.
In der folgenden Abbildung wurde die Regressionsgerade anhand der roten Punkte berechnet: y = 25.6965 * x + 391.5246


Also würde in diesem Beispiel die 32. Messung einen Co2-Wert über 1200 ppm haben. Dementsprechend würde nach ca. 43 Minuten nachdem die Personen reingekommen sind, der Co2-Wert den kritischen Wert erreichen.
Wichtig bei diesem Beispiel ist zu beachten, dass man die lineare Regression unter bestimmten Bedingungen gemacht hat:
◼ | 22 Personen kommen rein
◼ | Der Co2-Wert liegt, bevor die Leute reinkommen, zwischen 400-450.
◼ | Da nach 10 Minuten Fenster geöffnet wurden, konnte man für die Berechnung der linearen
| Regression nur 8 Datenpunkte verwenden.
Um die optimale Dauer des Lüftens zu bestimmen, kann man nicht eine lineare Regression durchführen da der Co2-Wert nicht linear sinkt. Jedoch kann man anhand folgender Abbildung eine Aussage treffen, dass nach ca. 12.5 Minuten der Co2-Wert bereits unter 500 ist, welcher für eine gute Raumluft spricht.


Auch hier sind wieder folgende Bedingungen zu beachten:
◼ | Der Co2-Wert liegt, bevor die Leute raus gehen, knapp bei 900.
◼ | Es wurden in der Pause 3 Fenster geöffnet.
Um allgemeine Aussagen bezüglich optimalen Zeitpunktes der Pause (inkl. Lüften) und der optimalen Dauer der Pause (inkl. Lüften), müsste man diesen Vorgang für alle Kombinationen durchführen. Dafür bräuchte man deutlich mehr Daten, und mehr Zeit.

Abbildung 13 Optimaler Zeitpunkt für die Pausen mittels linearer Regression

Abbildung 14 Optimaler Zeitpunkt zum Schliessen der Fenster

Welche weiteren Erkenntnisse lassen sich ableiten

Pausen sind wichtiger als nur Lüften:

Wie man in den 3 vorherigen Unterkaptiel erkennen konnte, steigt der Co2-Wert, wenn Personen sich im Raum befinden, auch wenn gelüftet wird.
Man erkennt, dass nur die Pausen (in denen auch gelüftet wird aber keine Personen sich im Raum befinden) wirklich einen Einfluss auf die Verringung des Co2-Wertes haben.
Somit kann man sagen, dass viel mehr Wert auf die Pausen gelegt werden sollte (in denen selbstverständlich auch gelüftet werden muss) als auf das Lüften an sich.

Kurzes Stosslüften bei kühleren Aussentemperaturen:

Bei kühleren Aussentemperaturen, wie das in diesen Messdaten oftmals der Fall war, kann durch andauernd geöffnete Fenster viel Heizenergie verschwendet werden. In dem untenstehenden Plot ist gut sichtbar, dass um 09:30 Uhr drei Fenster geöffnet werden. Gleichzeitig verlassen die Schüler das Schulzimmer für eine grössere Pause oder eine Lektion in einem anderen Schulzimmer (09:30-10:45 Uhr). Als Folge sinkt der Kohlenstoffdioxid rasch auf ein niedriges Level (09:40 ca. 500 ppm.). Somit ist in diesem Beispiel die Luftqualität nach 10 Minuten hervorragend. Unsere Raumtemperatur beträgt zu diesem Zeitpunkt 24° Celsius (Messung beeinflusst von der Heizungsabwärme), was einen Verlust von ca. 1,5° Celsius bedeutet. Dennoch bleiben weiterhin alle drei Fenster voll geöffnet, bis zur Rückkehr der Schüler/innen (10:45 Uhr). Bis dahin hat sich die Raumtemperatur auf 20,5° Celsius runtergekühlt.


Soll das Klassenzimmer nun wieder auf die Standard-Raumtemperatur von 25° Celsius erhitzt werden, wird eine Energie von ca. 1'100 KJ anstelle der optimalen 250 kJ (1° Celsius/1m³ = 1,32KJ). Somit wurde in diesem Beispiel mehr als vier Mal so viel Heizenergie benötigt, um das Klassenzimmer wieder auf die Ausgangs Temperatur zu erhöhen (Berechnungen stark vereinfacht).

Abbildung 15 Co2- und Raumtemperatur-Verlauf (in Bezug auf Heizenergie)

Korrelation Raumtemperatur- Co2-Gehalt

Eine weitere Feststellung ist eine Korrelation zwischen der Raumtemperatur und den Co2-Werten. Die sinkende Raumtemperatur war in den Messungen ein gutes Nachzeichen auf einen gesunkenen und somit tiefen Co2-Wert. Somit wäre es mit genaueren Untersuchungen tendenziell möglich einen teuren Co2-Sensor durch einen günstigeren Temperatur-Sensor auszutauschen. Wichtig: hierbei ist zu beachten, dass uns lediglich Messdaten von dem Monat April vorliegen. Somit können keine Temperaturschwankungen in den restlichen Monaten vorhergesagt werden. Dasselbe verhalten wurde auch anhand der Luftfeuchtigkeit untersuch, dabei konnten nur an bestimmten Tageszeitpunkten Korrelationen, festgestellt werden. Vermutlich hat das Wetter einen zu grossen Einfluss wie beispielsweise Regenschauer.


Bestätigung / Widerlegung Ergebnisse Dritter

Recherchiert man im Internet über das Thema «Klassenzimmer richtig lüften» gelangt man schnell, aufgrund der Corona-Pandemie, auf die Internetseite des BAG (BAG, 2022).
Dort wird in mehreren Arten erklärt, worauf beim Lüften geachtet werden soll.
So gibt es zum Beispiel ein Infoblatt «Lüften in Schulen während der Corona-Epidemie» (www.schulen-lueften.ch, 2022), darin wird unter anderem zu den «Lüftungsregeln» (www.simaria.ch, 2022) verwiesen. Diese bestehen aus 8 Regeln (siehe Abbildung rechts). Es wird erwähnt, dass bei den grossen und kleinen Pausen vollständig gelüftet werden sollte und dass alle Fenster immer vollständig geöffnet sein
sollten. Diese 2 Punkte würden wir ebenfalls bestätigen.
Jedoch sollte man achten das bei den Pausen so viel Leute


wie möglich das Klassenzimmer auch verlassen sollten, damit der Co2-Wert auch wirklich sinken kann.
Wie unter «Zusammenhang Luftqualität und Lüftungs-Frequenz» bereits gezeigt wurde.

Abbildung 16 Co2- und Raumtemperatur-Verlauf

Abbildung 17 8 Lüftungsregeln

## Lessons Learned

Probleme:

Das Lösen der Aufgabenstellung zog mehrere Probleme mit sich, welche es zu lösen galt. Ein immer wiederkehrendes Problem wahren fehlende Funkaufbauten zwischen den Slave-Microcontroller und dem Master via BLE. Besonders knifflig war dabei die Fehlerbehebung, da die Fehler ohne Systematik auftraten. Mit verschiedenen Lösungsansätzen wie einem Watchdog, welcher die Microcontroller neustartet, sobald für 2 min keine BLE-Verbindung aufgebaut wurde und dem Erstellen eines Log-Files konnte das Problem bis zu Schluss leider nicht behoben werden. Speziell war das häufige Auftreten des Problems auf einem bestimmten Microcontroller, auf welchem dieselbe Software aufgespielt war. Dieser wurde anschliessend durch einen neuen Microcontroller ersetzt. Zudem wurde auch sein Standort verändert. Durch die fehlenden Daten der Microcontroller eins und zwei wurde hauptsächlich mit dem Device drei Daten gesammelt, welches an einem ungünstigen Standort neben Fenster und unterhalb der Heizung positioniert wurde. Die Wahl des Standorts dieses Devices war aufgrund der Verkabelung mit den Magnetschalter der Fenster stark eingeschränkt, was keine bessere Positionierung ermöglichte.
Als Lesson Learned kann somit eine noch bessere Planung, in welcher vor allem die Ausfall Stabilität besser getestet werden sollte, mitgenommen werden.

Eine weitere Problemstellung, die sich während der Auswertung ergab, waren die erhobenen Personendaten der Lehrpersonen, welche an bestimmten Tagen einige Unstimmigkeiten aufwiesen.


Wir sehen ein steigender Co2-Wert um 10:45 Uhr, ohne dass sich laut Angaben der Lehrpersonen, Personen in dem Raum aufgehalten haben. Da genügend Daten zur Auswertung vorhanden waren, konnten wir auf solche Tage oder Stunden verzichten. Die Personendaten hätten grob mit Absprache der Lehrpersonen und einem Blick auf den Stundenplan rekonstruiert werden können.
Ausserdem wurden am letzten Tag einige Datenpunkte mit über 5000 ppm Co2-Gehalt gemessen. Diese wurden als Ausreisser vermerkt und bewusst ignoriert, diese Vorgehensweise führte zu keinerlei Problemen, da es nur einige wenige Datenpunkte betraf. Grund dafür könnte beispielsweise das absichtliche Anpusten der Sensoren sein.

Abbildung 18 Unstimmigkeit "Personen im Raum"

## Abbildungsverzeichnis

## Literaturverzeichnis

(28. 05 2022). Von www.schulen-lueften.ch: https://www.schulen-lueften.ch/upload/downloads/BAG_Lueften_Coronavirus_DE_201106.pdf abgerufen
(28. 05 2022). Von www.simaria.ch: https://www.simaria.ch/upload/simaria_help/Simaria_Lueftungsregeln_DE.pdf abgerufen
BAG, B. f. (28. 05 2022). bag.admin.ch. Von https://www.bag.admin.ch/bag/de/home/das-bag/aktuell/news/news-19-11-2020.html abgerufen

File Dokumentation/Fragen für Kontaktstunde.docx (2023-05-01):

Fragen Smartclassroom

System-Architektur APIs/Protokolle/Datenformate:

- Grafik zeigen? Was fehlt noch?

Software Module/Sequenzdiagramm:

- Ist Grafik io?

Datenbank Entitäten/Schema/…:

- Reicht das?

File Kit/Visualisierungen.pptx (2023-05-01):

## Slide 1

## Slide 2


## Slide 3


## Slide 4


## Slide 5


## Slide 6


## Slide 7


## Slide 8


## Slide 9


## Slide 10


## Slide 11


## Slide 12


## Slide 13


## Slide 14


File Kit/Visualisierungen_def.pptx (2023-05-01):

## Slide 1

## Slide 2


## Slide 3

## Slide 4

Massnahmen 1

Teaching im Team

Teaching mit Fachexperten
IDB Netztwerktechnik (Luca, Yannic)
CDE2 Datenbank REST Luca, Yannic
GDV -> Yannic, Luca
DDI (Y/T)

Selbststudium
Hardware (Y/T/L)
Netzwerktechnik (Y/T/L)
Datenbank (Y/L)
Explorative Datenanalyse (Y/T/L)
Onlinekurs Datenbanken (Y)

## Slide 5

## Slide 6

Massnahmen 2

Teaching im Team
Code T → Y/L
Hardware T → Y/L
Datenbank Y → T/L
Notebook L → T/L

Teaching mit Fachexperten

Selbststudium
Lernmaterial IDB (Y/L)
Lernmaterial DDI (Y/T)

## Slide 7

(In Bearbeitung)

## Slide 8

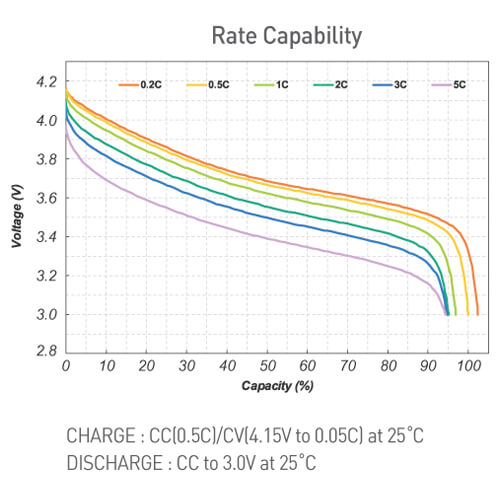
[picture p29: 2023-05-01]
Hardware/Akku/charge-and-discharge-rate-curve.jpg

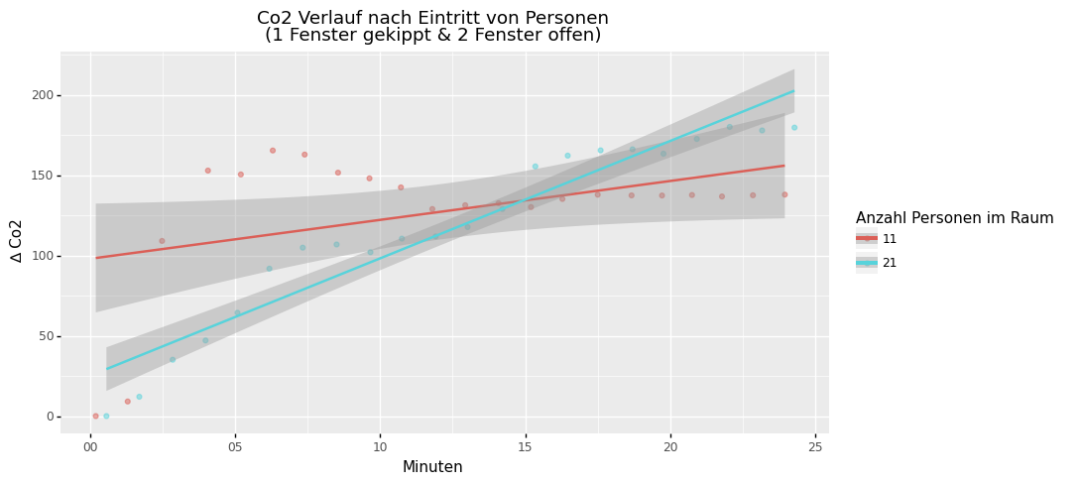
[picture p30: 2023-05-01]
Data_Analysis/Plots/Co2_steigung_1g_2o.png

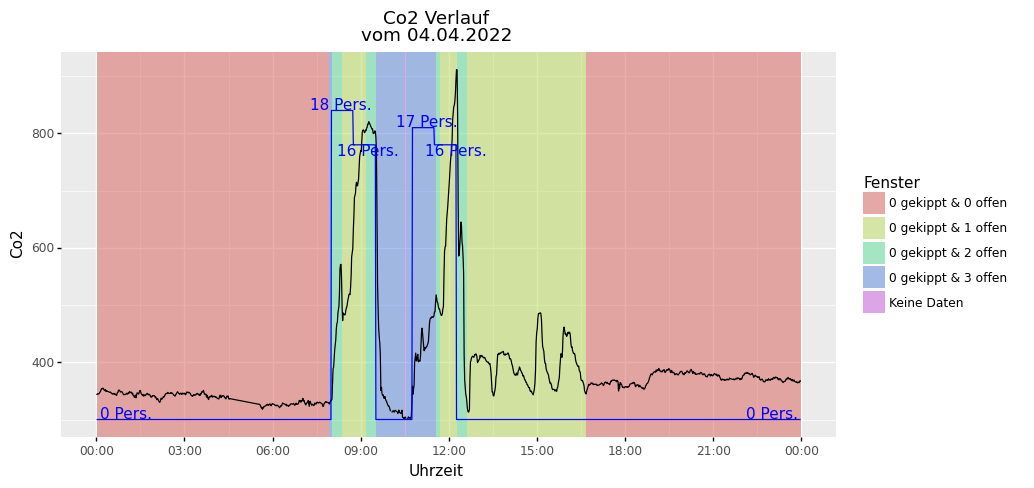
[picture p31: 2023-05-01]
Data_Analysis/Plots/Co2_0404.png

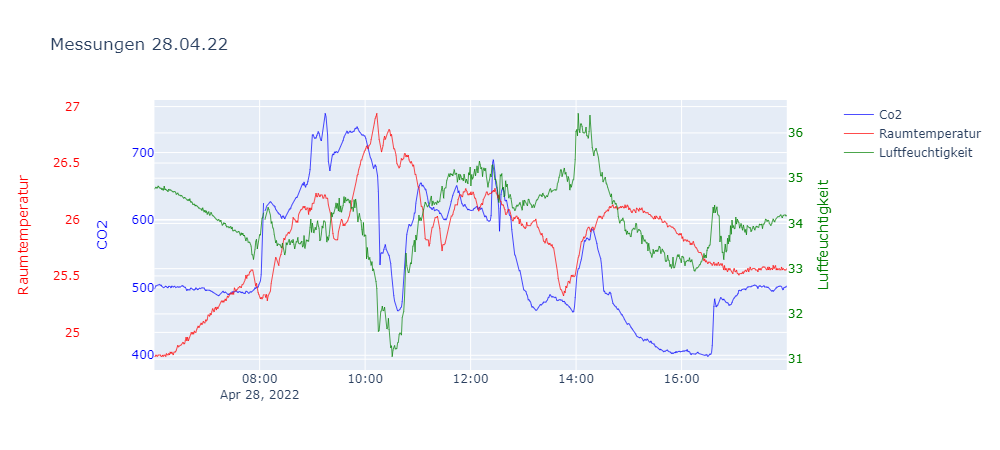
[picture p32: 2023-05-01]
Data_Analysis/Plots/korrelationen beides.png

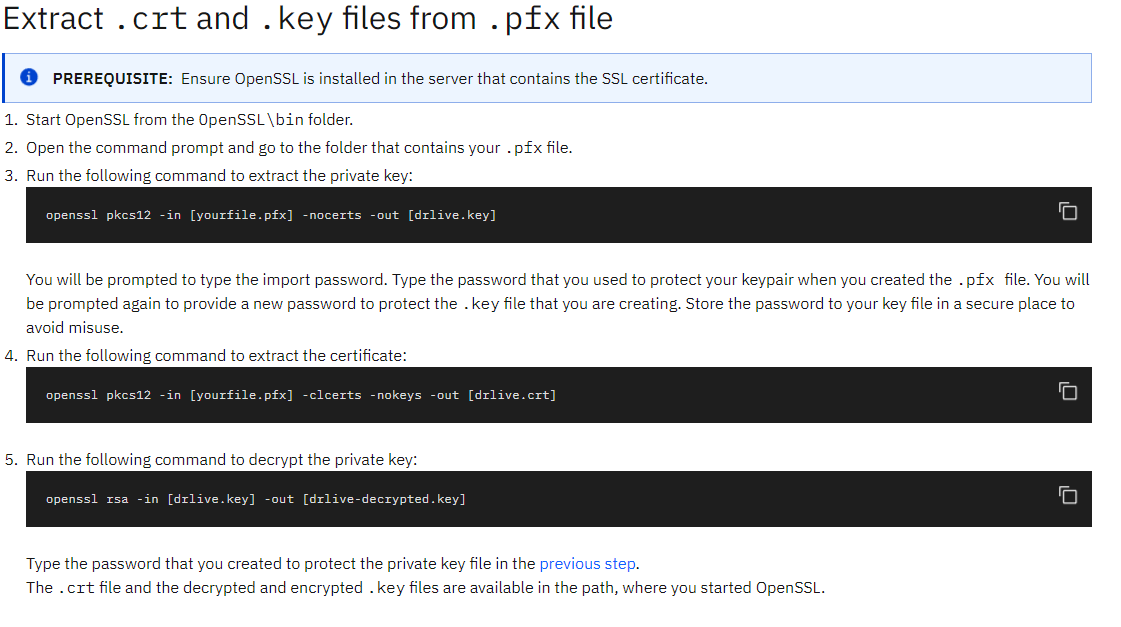
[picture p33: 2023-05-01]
Abgabe komplett/Server/SSL/export certificate and decrypted key for server.png

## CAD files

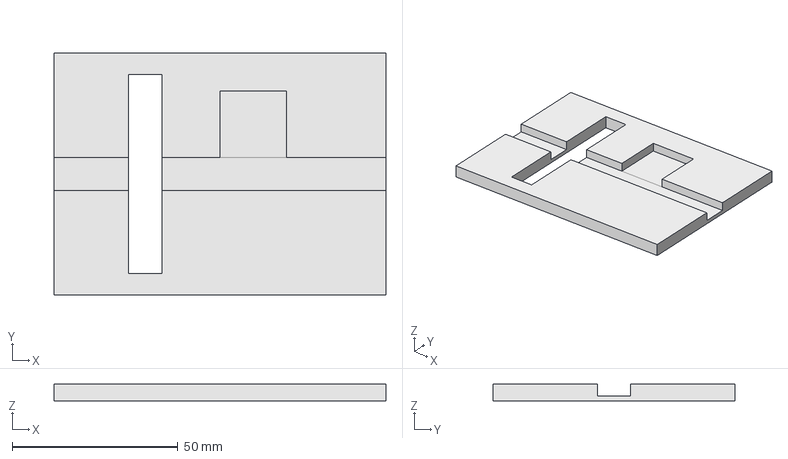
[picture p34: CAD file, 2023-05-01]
Box/Deckel_def.FCStd
100.0 x 73.0 x 5.00 mm

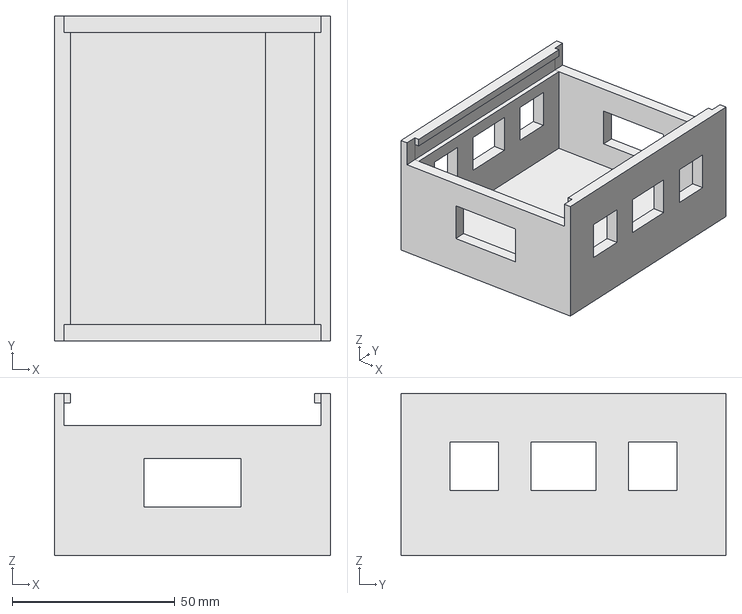
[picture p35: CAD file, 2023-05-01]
Box/Box_raspberry_def.FCStd
85.0 x 100.0 x 50.0 mm

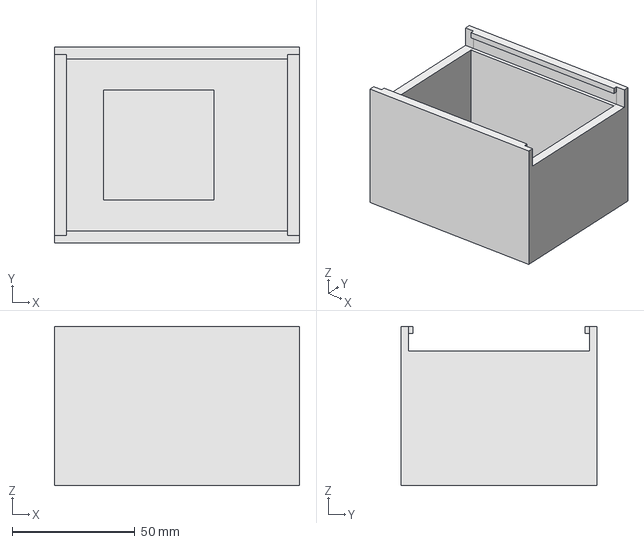
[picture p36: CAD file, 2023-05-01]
Box/Box_def.FCStd
100.0 x 80.0 x 65.0 mm

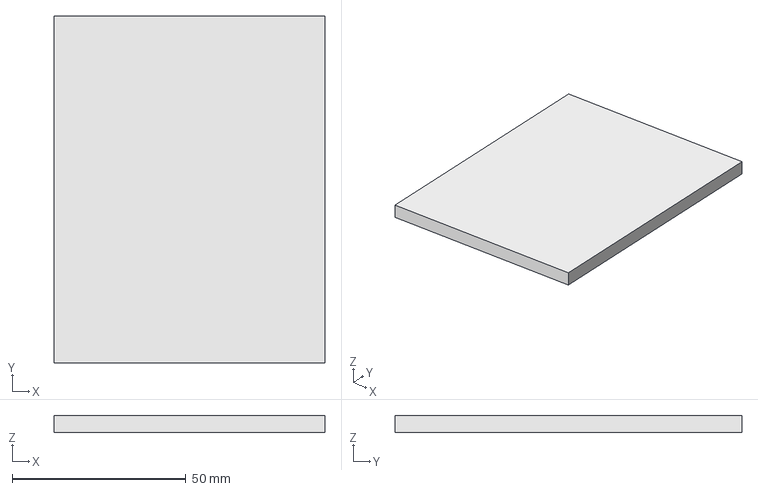
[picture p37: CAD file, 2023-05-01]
Box/Deckel_raspberry_def.FCStd
78.0 x 100.0 x 5.00 mm

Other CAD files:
Box/Box_def.stl
Box/Box_raspberry_def.stl
Box/Deckel_def.stl
Box/Deckel_raspberry_def.stl

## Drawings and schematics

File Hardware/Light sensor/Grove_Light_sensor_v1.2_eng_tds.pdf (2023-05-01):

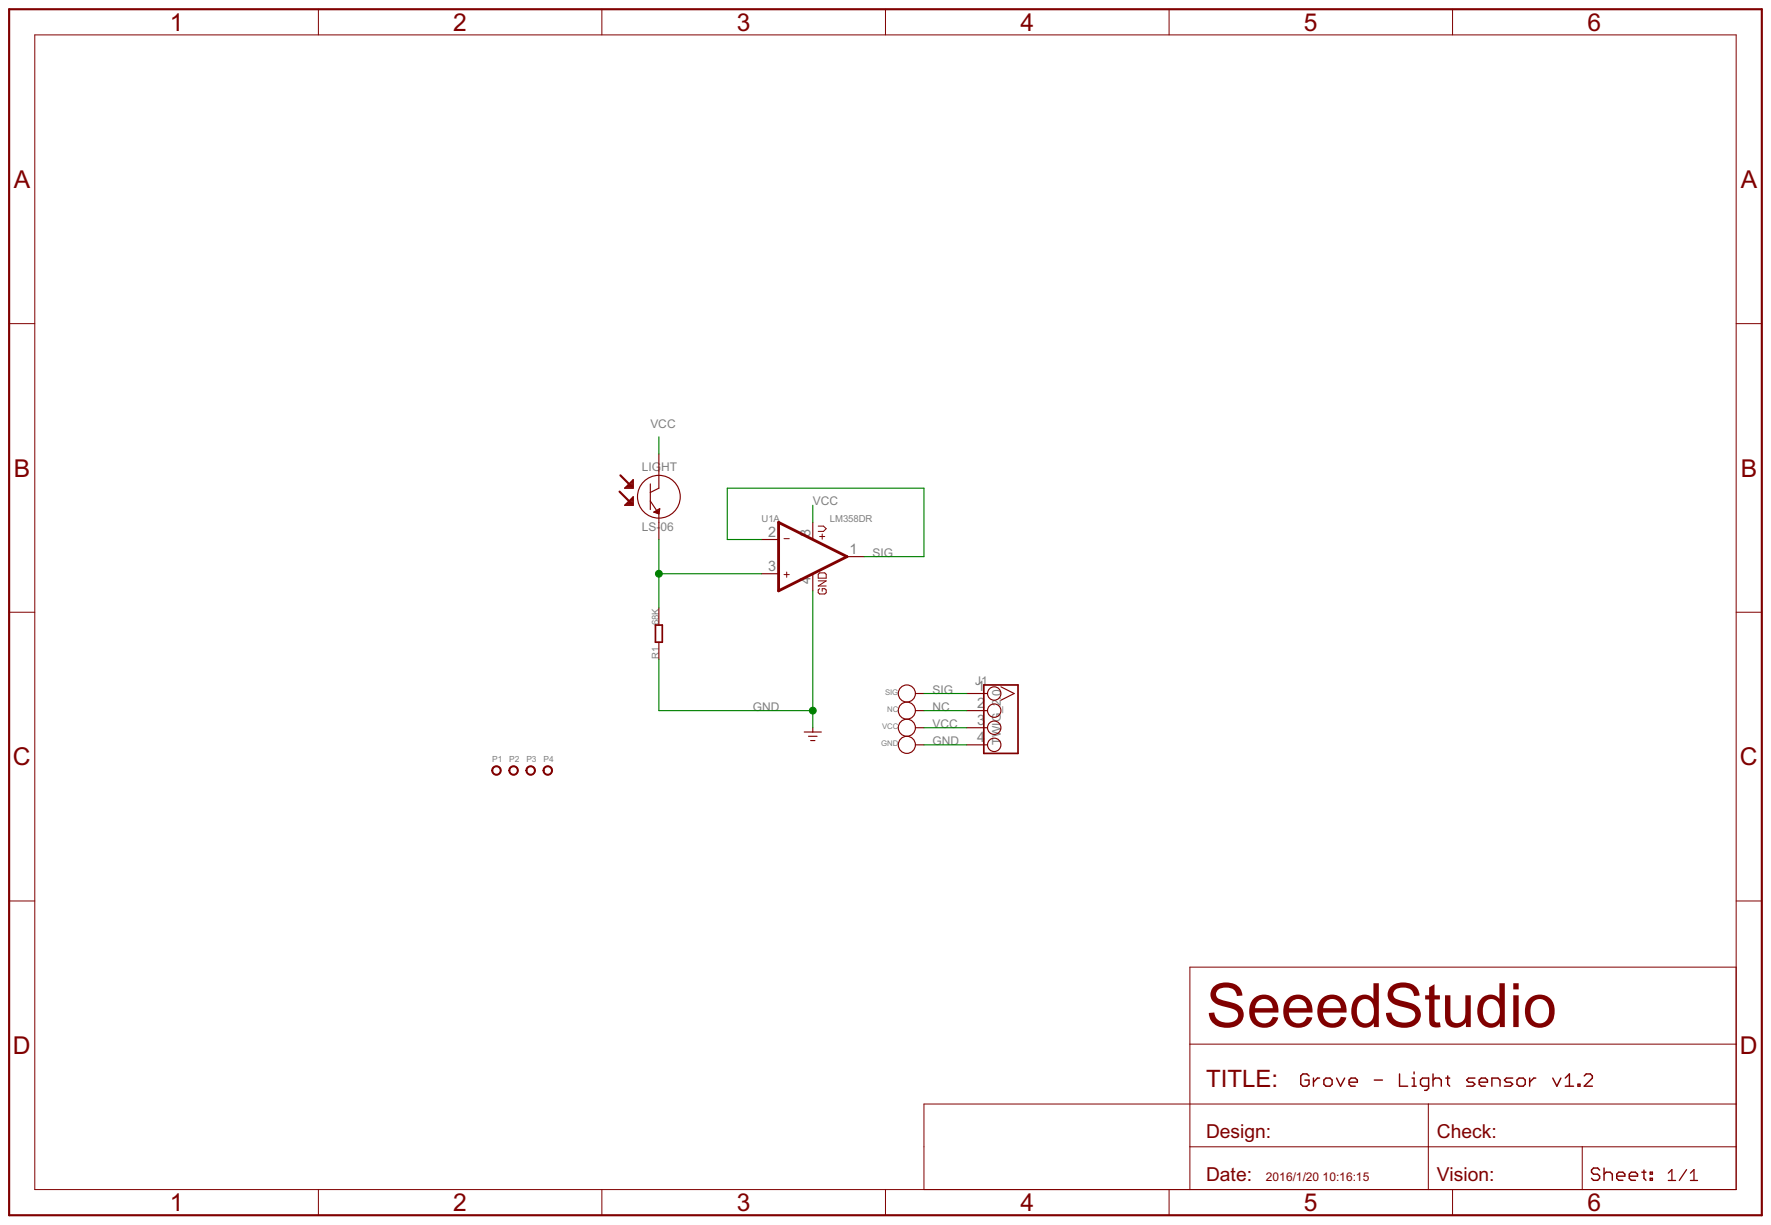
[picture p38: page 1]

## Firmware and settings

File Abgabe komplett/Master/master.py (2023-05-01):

from datetime import datetime
import socket
import ssl
from time import monotonic, sleep
import _bleio
from adafruit_ble.advertising.standard import ProvideServicesAdvertisement
from adafruit_ble.services.nordic import UARTService
from adafruit_ble import BLEConnection
import adafruit_ble
import json
import os
from iterators import TimeoutIterator

#log file appender
log_fileName = str(os.path.dirname(os.path.realpath(__file__))) + "/log.txt" #full path to cache script
def Write_To_Log_File(clssName:str, text:str):
    """
    Write text to log file 
    format: 'monotonic time': 'clssName': 'text'
    """
    
    timestamp = monotonic()
    with open(log_fileName, "a+") as fd:
        fd.write(str(timestamp) + ": " + clssName + ": " + text + "\n")
        fd.flush()

class SSL:
    def __init__(self, host= 'solarbroom.com', port= 443) -> None:
        self.HOST = host
        self.PORT = port
    
    def __read_from_conn(self, conn:ssl.SSLSocket):
        """
        read message from connection
        returns: received string 
        
        this method can raise an error
        """

        Write_To_Log_File("SSL", "start reading from connection")

        message = "" #message stored here
        while True:
            data = conn.recv(buflen=1024) #read 1024 bytes

            #if no data received
            if data == b"":
                raise Exception(f"No data received.\nAlready read data.\n{message}")

            #decode received bytes and store characters in message (check if endchar received)
            for chr in bytes.decode(data):
                #if endchar received -> return message
                if chr == "\n":
                    Write_To_Log_File("SSL", "sucessfully read from connection")

                    return message

                else: #otherwise add char to message
                    message += chr

    def __Send_Read(self, message:str) -> str:
        """
        Sends message and reives answer -> if a failure occures: None is returned
        """

        #try creating socket
        try:
            Write_To_Log_File("SSL", "start creating binding socket")

            bindsocket = socket.create_connection((self.HOST, self.PORT), timeout=5)
            bindsocket.setsockopt(socket.SOL_SOCKET, socket.SO_REUSEADDR, 1)

            Write_To_Log_File("SSL", "successfully created binding socket")

            print("BindingSocket successfully created")

        except Exception as ex:
            #close eventual open bindsocket
            try:
                bindsocket.close()
            except:
                pass
            
            Write_To_Log_File("SSL", f"exception occured in create binding socket: {ex}")

            print(f"Exception occured during creating bindingSocket: {ex}")
            return None

        #try create sslcontext
        try:
            Write_To_Log_File("SSL", "start wrapping socket")

            context = ssl._create_unverified_context() #default context had a problem with certificate (no idea why... tried to fix it but failed) -> unverified_context: no server certificate check          
            conn = context.wrap_socket(bindsocket, server_hostname=self.HOST)
            bindsocket.close() #close original socket

            conn.settimeout(5) #set read/write timeout to 5 seconds

            Write_To_Log_File("SSL", "socket successfully wrapped")

            print("SSLSocket successfully created")

        except Exception as ex:
            #close eventual open bindsocket
            try:
                bindsocket.close()
            except:
                pass

            #close eventual open sslsocket
            try:
                conn.close()
            except:
                pass

            Write_To_Log_File("SSL", f"wrapping socket failed: {ex}")

            print(f"Building ssl connection failed: {ex}")    
            return None


        ##send receive message##

        answer = "" #answer from server stored here
        returnNone = False #true if error occured and None should be returned

        #send data to server and expect answer
        try:
            message_bytes = str.encode(message + "\n") #convert to bytes

            print(f"Sending message: {message_bytes}")

            Write_To_Log_File("SSL", "start sending text to server")
            conn.sendall(message_bytes) #send message
            Write_To_Log_File("SSL", "text successfully sent to server")

            print("Message Sent")

            try:
                Write_To_Log_File("SSL", "start reading from server")
                answer = self.__read_from_conn(conn) #read answer
                Write_To_Log_File("SSL", "successfully read data from server")

                print(f"Answer received: {answer}")

            except Exception as ex:
                returnNone = True #set flag

                Write_To_Log_File("SSL", f"exception occured in read_from_conn: {ex}")

                print(f"Exception occured during receiving answer from server: {ex}")

        except Exception as ex:
            returnNone = True #set flag

            Write_To_Log_File("SSL", f"exception occured in send data to server: {ex}")

            print(f"Exception occured during sending data to server: {ex}")

        finally:
            
            #close connection
            try:
                conn.shutdown(socket.SHUT_RDWR)
            except Exception as ex:
                print(f"Exception occured in shutdown connection: {ex}")

            try:
                conn.close()
            except Exception as ex:
                print(f"Exception occured in close connection: {ex}")

               
        if returnNone: #error occured and None should be returned
            return None
        else: #data sent successfully
            return answer

    def __Write(self, message: str) -> bool:
        """
        Send message to server
        """
        
        try:
            received = self.__Send_Read(message)

            if received == None: #exception during sending/receiving data
                return False

            elif received == "confirmed": #server stored data successfully
                return True

            elif received == "failed": #data failed to store
                return False

            else:
                raise Exception("unknown confirmation message received")

        except Exception as ex:
            print(f"Unable to send message to server: {ex}")
            return False

    def Send_Jsons(self, jsons:list) -> bool:
        """
        This method sends all measurements as json to server

        params:
        jsons: measurements as list containing jsons
        """
        
        stringified_jsons = []
        for json_ in jsons:
            stringified_jsons.append(json.dumps(json_))

        jsons_appended = ";".join(stringified_jsons) #convert jsons and join them with ';' as separator

        return self.__Write("data~"+jsons_appended)
            
class Cache:
    def __init__(self, relative_fileName = "cache") -> None:
        Write_To_Log_File("Cache", "init started")

        self.__script_dir = os.path.dirname(os.path.realpath(__file__)) #<-- absolute dir the script is in
        self.__full_fileName = str(self.__script_dir) + "/" + relative_fileName #full path to cache script

        self.__cache_cleanup_or_creation()#delete invalid data or create file if not existing

        Write_To_Log_File("Cache", "init stopped")

    def __cache_cleanup_or_creation(self):
        try:
            #create file if not exists
            with open(self.__full_fileName,"a+") as fd:
                pass

            #read content of caches
            with open(self.__full_fileName, "r") as fd:
                content:str = fd.read()

            #check if strings are valid jsons
            json_files = []
            for json_string in content.split("\n"):
                if len(json_string) > 0:
                    try:
                        json_files.append(json.loads(json_string))
                    except:
                        print("Measurement lost during cache cleanup...")

            #clear cache
            with open(self.__full_fileName, 'w'):
                pass

            #append jsons to cache
            with open(self.__full_fileName, 'a') as fd:
                for json_file in json_files:
                    fd.write(json.dumps(json_file) + "\n")

        except Exception as ex:
            print(f"Cache cleanup encountered an error: {ex}")

    def Cache_Append_Json(self, json_file:json) -> bool:
        try:
            Write_To_Log_File("Cache", "appending json started")
            #append jsons to cache
            with open(self.__full_fileName, 'a') as fd:
                fd.write(json.dumps(json_file) + "\n")

            Write_To_Log_File("Cache", "appending json successfully finished")

            return True

        except Exception as ex:
            Write_To_Log_File("Cache", f"exception occured in changing json: {ex}")

            print(f"Cache append encountered an error: {ex}")
            return False

    def Cache_Read(self) -> list or None:
        try:
            Write_To_Log_File("Cache", "read cache started")

            #read content of caches
            with open(self.__full_fileName, "r") as fd:
                content:str = fd.read()

            #check if strings are valid jsons and store them
            json_files = []
            for json_string in content.split("\n"):
                if len(json_string) > 0:
                    try:
                        json_files.append(json.loads(json_string))
                    except:
                        print("Measurement lost during cache reading...")

            Write_To_Log_File("Cache", "read cache successfully stopped")

            return json_files   

        except Exception as ex:
            Write_To_Log_File("Cache", f"exception occured in read_cache: {ex}")

            print(f"Cache read encountered an error: {ex}")
            return None

    def Cache_Clear(self) -> bool:
        try:
            Write_To_Log_File("Cache", "start cache clear")

            #clear cache
            with open(self.__full_fileName, 'w') as fd:
                pass

            Write_To_Log_File("Cache", "cache clear successfully finished")

            return True

        except Exception as ex:
            Write_To_Log_File("Cache", f"exception occured in cache clear: {ex}")

            print(f"Cache clear encountered an error: {ex}")
            return False

class BLE:
    def __init__(self, device_names: list) -> None:
        """
        Init bluetooth

        params:
        device_names (list of strings): device_names of measurement devices
        """

        Write_To_Log_File("BLE", "init started")

        self.__device_names = device_names
        
        # CircuitPython <6 uses its own ConnectionError type. So, is it if available. Otherwise,
        # the built in ConnectionError is used.
        connection_error = ConnectionError
        if hasattr(_bleio, "ConnectionError"):
            connection_error = _bleio.ConnectionError

        # PyLint can't find BLERadio for some reason so special case it here.
        self.__ble = adafruit_ble.BLERadio()  # pylint: disable=no-member

        Write_To_Log_File("BLE", "init stopped")

    def __Scan_For_Advertizements(self, timeout_s=10.0) -> dict:
        """
        Scan for advertizements 

        params:
        timeout: timeout of scanning (iteratorTimeout = timeout_s + 5; scanTimeout = timeout_s)
        """
        
        measurement_device_advertizements = {} #advertizements of measurement devices are stored here

        try:
            print("scanning")
            Write_To_Log_File("BLE", "start advertizement scan")

            found_addr = set()
            it = TimeoutIterator(self.__ble.start_scan(ProvideServicesAdvertisement, timeout=timeout_s), timeout_s + 5) #TimeoutIterator used because of: self.__ble.start_scan does not yield anything if nothign is found 
            for advertisement in it: 
                
                #if timeout
                if advertisement == it.get_sentinel():
                    Write_To_Log_File("BLE", "timeout occured during scanning advertizements")

                    print("Iterator timed out... interrupt")
                    break

                addr = advertisement.address #get address of device

                #if address not found already
                if addr not in found_addr:
                    found_addr.add(addr) #add  to found

                    name_raw = advertisement.complete_name

                    if not name_raw:
                        continue

                    name = name_raw.strip("\x00")

                    if name in self.__device_names: #ceck if devicename matches with a name of predefined deviceName list
                        measurement_device_advertizements[name] = advertisement #store advertizement

                        print(f"Device with name: {name} and address: {addr} found")
                        Write_To_Log_File("BLE", f"Device with name: {name} and address: {addr} found")

        except Exception as ex:
            print(f"Exception occured in __Scan_For_Advertizements: {ex} ->  restarting bluetooth")
            Write_To_Log_File("BLE", f"Exception occured in __Scan_For_Advertizements: {ex} ->  restarting bluetooth")

            os.system("sudo /etc/init.d/bluetooth  restart")

        self.__Stop_Scan_Save() #stop scan

        print("scan done")

        Write_To_Log_File("BLE", "scan successfully stopped")

        return measurement_device_advertizements

    def __Stop_Scan_Save(self):
        try:
            self.__ble.stop_scan()
        except:
            pass

    def __TryConnect_ToDevice(self, device_advertisements: ProvideServicesAdvertisement, timeout=10.0) -> list:
        """
        This method tries to connect to all advertizements

        returns:
        keys from advertizements that was unable to connect to
        """

        try:
            Write_To_Log_File("BLE", "connect to device started")

            if UARTService not in device_advertisements.services:
                raise Exception("UART not available for this device")

            Write_To_Log_File("BLE", "successfully tried to device (does not mean that we have successfully connected)")

            return self.__ble.connect(device_advertisements, timeout=timeout)

        except Exception as ex:
            Write_To_Log_File("BLE", f"exception occured in try_connect_to_device: {ex}")
            print(f"Was unable to connect to device:\n{ex}")
            return None

    def __Disconnect_FromDevice_Save(self, connection: BLEConnection):
        try:
            connection.disconnect()

        except:
            pass

    def __Request_Measurements_from_connection(self, connection: BLEConnection, start_read_timeout_s=4.0):
        """
        This method requests all measurements from a device

        returns:
        json
        """
        
        json_response: json = None

        try:
            Write_To_Log_File("BLE", "request measurement from connection started")

            if UARTService not in connection:
                raise Exception("UART not available for this device")

            #use UARTService for communication
            uart:UARTService = connection[UARTService]
            uart.timeout = start_read_timeout_s

            uart.write(str.encode("measure_request\n", encoding="utf-8")) #send read measurements request

            message = ""
            while True:
                #wait until bytes arrived -> raise exception if no data arrived for too long
                time_ = monotonic()
                while uart.in_waiting < 1:
                    if not connection.connected:
                        raise Exception("connection lost")

                    #if timeout
                    if monotonic() - time_ >= start_read_timeout_s:
                        raise Exception("connection timed out")

                byte_:bytes = uart.read(1) #read a byte

                if byte_ == None:
                    raise Exception("Connection timeout")

                received_char = str(byte_.decode("utf-8"))

                if received_char:
                    if received_char != "\n":
                        message += received_char

                    else:
                        json_response = json.loads(message)
                        break

            Write_To_Log_File("BLE", "successfully requested measurements from connection")
            
        except Exception as ex:
            Write_To_Log_File("BLE", f"exception occured in request_measurements_from_connection: {ex}")

            print(f"Exception occured in __Request_Measurements_from_connection: {ex}")

        return json_response
                
    def Start_Request(self, max_number_of_tries:int = 5):
        """
        Start measure request from all devices

        params:
        max_number_of_tries: number of reties if connection to a device failed
        """
        
        jsons:json = json.loads(json.dumps({deviceName:"BLE_error" for deviceName in self.__device_names})) #create json with bleError as standard entry for every device

        Write_To_Log_File("BLE", "start advertizement scan")
        adverts = self.__Scan_For_Advertizements() #scan for advertizements
        Write_To_Log_File("BLE", "successfully finished advertizement scan")

        timeStamp = datetime.now() #get current time (timestamp of measurement in database)
        for deviceName in list(adverts.keys()): #iterate over deviceNames
            ad = adverts[deviceName] #get advertizement

            number_of_tries = 0
            while number_of_tries < max_number_of_tries: #retry max X times -> if connection cannot be established bleError is the value of entry for this device
                print(f"Try connect to  {deviceName}")

                Write_To_Log_File("BLE", f"try connect to: {deviceName}")

                connection = self.__TryConnect_ToDevice(ad) #connect to advertizement

                if (connection != None): #if connection established
                    print(f"Successfully connected to {deviceName} -> start reading")
                    Write_To_Log_File("BLE", f"Successfully connected to {deviceName} -> start reading")

                    answer = self.__Request_Measurements_from_connection(connection) #request and get measurements from device

                    Write_To_Log_File("BLE", f"Finished reading from {deviceName} -> disconnect")
                    print(f"Finished reading from {deviceName} -> disconnect")

                    self.__Disconnect_FromDevice_Save(connection) #disconnect if a connection was opened

                    Write_To_Log_File("BLE", f"Disconnected from {deviceName}")
                    print(f"Disconnected from {deviceName}")

                    #getting data was successful
                    if answer != None:
                        jsons[deviceName] = answer #override bleError with received measurements

                        print(f"Successfully got data from {deviceName}")
                        Write_To_Log_File("BLE", f"Successfully got data from {deviceName}")

                    else: #getting measurements was not successful (bleError)
                        Write_To_Log_File("BLE", "Successfully connected to {deviceName} but was unable to get data")
                        print(f"Successfully connected to {deviceName} but was unable to get data")
                        
                    break #end 

                else: #connection failed -> retry max X times
                    Write_To_Log_File("BLE", f"Was unable to connect to {deviceName}")
                    print(f"Was unable to connect to {deviceName}")

                number_of_tries += 1 #increment counter

        return (timeStamp, jsons)

#init
server = SSL()
ble = BLE(["Device1", "Device2", "Device3"]) #all devices that master has to listen for is given as parameter here
cache = Cache()
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

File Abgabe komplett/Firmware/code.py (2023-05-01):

import math
from time import monotonic, sleep
from adafruit_ble import BLERadio
from adafruit_ble.advertising.standard import ProvideServicesAdvertisement
from adafruit_ble.services.nordic import UARTService
from analogio import AnalogIn
from digitalio import DigitalInOut
from digitalio import Direction
from digitalio import Pull
import adafruit_dht
import adafruit_scd30
import board
import busio 
import json
import alarm
from microcontroller import watchdog
from watchdog import WatchDogMode

def Write_To_Log_File(clssName:str, text:str):
    """
    Write text to log file 
    format: 'monotonic time': 'className': 'text'
    """
    
    timestamp = monotonic()
    with open("/log.txt", "a+") as fd:
        fd.write(str(timestamp) + ": " + clssName + ": " + text + "\n")
        fd.flush()

class blueTooth:
    def __init__(self, deviceName: str, start_read_timeout_s=10.0):
        """
        Initialize bluetooth interface

        parameters:
        deviceName: name inside advertizement
        start_read_timeout_s: uart timeout
        """
        
        Write_To_Log_File("blueTooth", "init started")
        self.__ble = BLERadio()
        self.__ble.name = deviceName

        self.__uart = UARTService()
        self.__uart.timeout = start_read_timeout_s

        self.__advertisement = ProvideServicesAdvertisement(self.__uart)
        Write_To_Log_File("blueTooth", "init ble finished")

    def Advertise_Until_Connected_Sync(self):
        """
        This method advertizes and waits until a device connected to feather
        """

        #as long as not connected
        Write_To_Log_File("blueTooth", "advertizing started")
        while not self.__ble.connected:
            #try start advertizing
            try:
                self.__ble.start_advertising(self.__advertisement) 
            except:
                pass

            sleep(1) #sleep a second 

        self.__ble.stop_advertising() #stop advertising
        Write_To_Log_File("blueTooth", "advertizing stopped")

    def Is_Connected(self):
        return self.__ble.connected

    def Read_Message_Sync(self, timeout_s = 4.0) -> str:
        """
        This method reads incoming data

        params:
        timeout_ms (int) -> reading has to finish within timeout_ms
        """

        Write_To_Log_File("blueTooth", "message reading started")

        if not self.__ble.connected:
            raise Exception("not connected to a device")

        monotonic_time_s = monotonic()

        #wait until bytes arrived
        while self.__uart.in_waiting < 1:
            if not self.__ble.connected:
                raise Exception("connection lost")

            elif (monotonic() - monotonic_time_s) > timeout_s: #if looping for too long
                raise Exception("Timeout occured")

        bytes_ = self.__uart.readline()  #read a byte -> returns b'' if nothing was read.

        if bytes_ == None:
            raise Exception("Connection failed")

        message = str(bytes_.decode("utf-8"))
        message = message.rstrip("\n")
        message = message.rstrip("\r")

        Write_To_Log_File("blueTooth", "message successfully read")

        return message 
            
    def Write_Message_Sync(self, message: str):
        """
        This method writes message to master

        params:
        message: string that will be sent to master
        """
        
        Write_To_Log_File("blueTooth", "start writing message")

        msg = message + "\n" #add delimiter

        #write message to master with a delay of 100ns (this delay prevents master from bluetooth buffer overload)
        for msg_snippets in msg:
            buffer = str.encode(msg_snippets, "utf-8")

            self.__uart.write(buffer)
            sleep(0.0001)

        Write_To_Log_File("blueTooth", "successfully written message")
            
class SCD30_Sensor:
    def __init__(self, i2c_address = 0x61):
        """
        Initializes SCD30_Sensor (co2, temperature, humidity)
        """
        
        Write_To_Log_File("SCD30_Sensor", "init started")

        self.__i2c = busio.I2C(board.SCL, board.SDA, frequency=1000)  # for FT232H, use 1KHz
        self.__scd = adafruit_scd30.SCD30(self.__i2c, address=i2c_address)
        self.__scd.measurement_interval = 25 #set measurement intervall to 25s

        #buffer variables for measurements
        self.__temp_celcius = None
        self.__relHum_percent = None
        self.__co2_ppm = None

        Write_To_Log_File("SCD30_Sensor", "init finished")

    def __readSensors(self):
        """
        This method read values from senor
        """
        
        Write_To_Log_File("SCD30_Sensor", "reading measurements started")

        #read if new values available on sensor
        if self.__scd.data_available:
            self.__temp_celcius = float(self.__scd.temperature)
            self.__relHum_percent = float(self.__scd.relative_humidity)
            self.__co2_ppm = float(self.__scd.CO2)

        Write_To_Log_File("SCD30_Sensor", "reading measurements successfully finished")

    def Read_CO2_PPM(self) -> float:
        """
        Read CO2 in parts per million
        """
        
        Write_To_Log_File("SCD30_Sensor", "read_co2 sensor started")
        self.__readSensors()

        if self.__co2_ppm == None:
            raise Exception("SCD30_Sensor: CO2: No data available")

        Write_To_Log_File("SCD30_Sensor", "read_co2 sensor successfully finished")

        return self.__co2_ppm

    def Read_Rel_Hum_Percent(self) -> float:
        """
        Read relative humidity in %
        """

        Write_To_Log_File("SCD30_Sensor", "read_humidity started")

        self.__readSensors()

        if self.__relHum_percent == None:
            raise Exception("SCD30_Sensor: Humidity: No data available")

        Write_To_Log_File("SCD30_Sensor", "read_humidity successfully finished")

        return self.__relHum_percent
    
    def Read_Temp_Celcius(self) -> float:
        """
        Read air temperature in °C
        """
        
        Write_To_Log_File("SCD30_Sensor", "read_temp started")

        self.__readSensors()

        if self.__temp_celcius == None:
            raise Exception("SCD30_Sensor: Temperature: No data available")

        Write_To_Log_File("SCD30_Sensor", "read_temp successfully finished")

        return self.__temp_celcius
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
